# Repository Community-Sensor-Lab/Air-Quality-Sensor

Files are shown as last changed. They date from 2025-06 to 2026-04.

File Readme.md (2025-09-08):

<div align="center">

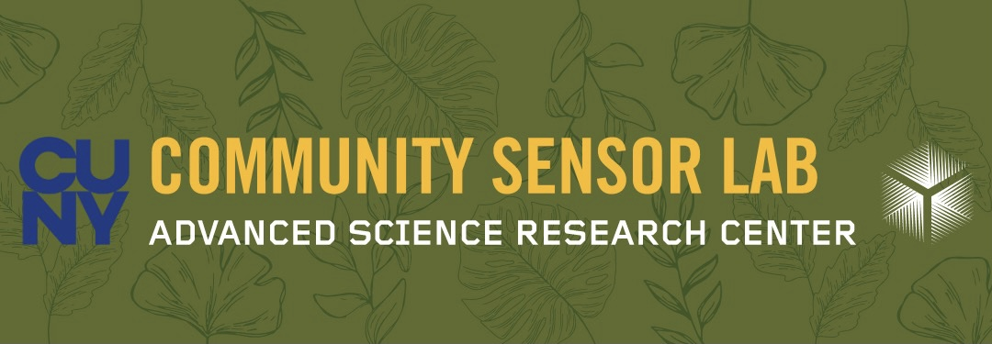
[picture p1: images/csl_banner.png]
Banner


</div>

#  Air Quality Sensor Assembly Guide

<div align="center">









*Build your own portable environmental monitoring station*

</div>

---

##  What You'll Build

<p align="center">
  
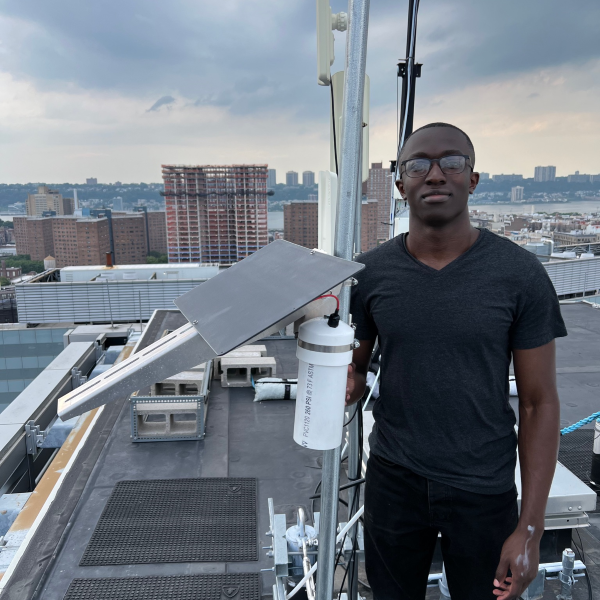
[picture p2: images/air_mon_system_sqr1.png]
  
</p>

> **A complete air quality monitoring system** that measures temperature, humidity, CO2, VOC/NOX, and particulate matter—with data logging, real-time display, and cloud connectivity.

###  Key Features
-  **Multi-sensor monitoring** (5 environmental parameters)
-  **SD card data logging** for long-term analysis  
-  **OLED display** for real-time readings
-  **WiFi connectivity** with Google Sheets integration
-  **Portable design** for indoor/outdoor use

###  Learning Outcomes
By completing this project, you'll gain hands-on experience with:
-  **Electronics assembly** and soldering techniques
-  **Arduino programming** and sensor integration
-  **Data visualization** and analysis methods
-  **IoT connectivity** and cloud services

---

##  Project Overview

| **Duration** | **Difficulty** | **Prerequisites** |
|:---:|:---:|:---:|
| 6-8 hours | Beginner | Basic computer skills |

*Multiple sessions recommended for best learning experience*

---

##  Complete Guide Contents

| Section | Title | Author | Description |
|:---:|---|---|---|
| **0** | [ Parts List](Contents/Parts-List.md) | *Mark* | Complete components inventory |
| **1** | [ Skills & Tools](Contents/1.%20Required-Skills-and-Tools.md) | *Lorena* | What you'll need to get started |
| **2** | [ Arduino Setup](Contents/2.%20Installing-Arduino-and-Getting-Started-2.3.6.md) | *Vincent* | Software installation & basics |
| **3** | [ Soldering Guide](Contents/3.%20Soldering-Pins-and-Headers-on-Boards.md) | | Hardware assembly techniques |
| **3.5** | [ WiFi Configuration](Contents/3.5%20Feather-M0-WiFi-Setup-Procedure.md) | *Fahmin: Flow chart* | Network connectivity setup |
| **4** | [ Component Assembly](Contents/4%20Breadboard-Assembly-and-Component-Code-Testing.md) | *Lorena* | Breadboard wiring & testing |
| **5** | [ Code Workshop](Contents/5.%20Code-Activity.md) | *Lorena* | Programming fundamentals |
| **6** | [ GitHub Integration](Contents/6.%20Downloading-CSL-AQS-Code-from-GitHub.md) | *Mark* | Source code management |
| **7** | [ Google Sheets Logging](Contents/7.%20Posting-to-Google-Logging-Spreadsheet.md) | *Vincent* | Cloud data integration |
| **8** | [ Data Visualization](Contents/8.%20How-to-Make-Data-Graphs-Lines-and-Time-Series.md) | *Ricardo* | Creating meaningful charts |
| **9** | [ PCB Design](Contents/9.%20Design-and-Assembly-of-PCB.md) | *Mark* | Printed Circuit Boards |
| **9.8** | [ Assembly of AQS Monitor on PCB Board](Contents/9.8%20Assembley-of-AQS-Monitor-on-PCB-Board.md) | | Soldering and mounting components onto the PCB |
| **10** | [ Final Assembly](Contents/10.%20AQS-PCB-Mount.md) | *Vincent* | Enclosure & mounting |

---

##  Quick Start

1. **Gather Materials** → Check the [Parts List](Contents/Parts-List.md)
2. **Setup Workspace** → Review [Skills & Tools](Contents/1.%20Required-Skills-and-Tools.md)
3. **Install Software** → Follow [Arduino Setup](Contents/2.%20Installing-Arduino-and-Getting-Started-2.3.6.md)
4. **Start Building!** → Begin with component assembly

---

##  Documentation Levels

| Guide Type | Best For | Link |
|---|---|---|
| **Quick Reference** | Experienced builders | *This README* |
| **Detailed Walkthrough** | First-time builders | [Comprehensive Guide](README-DETAILED.md) |

---

##  Perfect For

-  **STEM Education Programs**
-  **Students learning electronics**
-  **DIY environmental monitoring**
-  **Citizen science projects**

---

##  Contributing

Found an issue or have suggestions? We welcome contributions to improve this educational resource!

---

<div align="center">

**Transform your understanding of environmental monitoring while building something truly useful**





</div>

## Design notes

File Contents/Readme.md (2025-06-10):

# Air Quality Sensor Assembly Guide

## Introduction

This guide walks you through building an air quality monitoring system using Arduino-compatible components. The finished device will measure temperature, humidity, CO2, VOC/NOX, and particulate matter, log data to an SD card, display readings on an OLED screen, and optionally upload data to Google Sheets via WiFi.

This project is designed for students and educators in STEM programs, requiring basic electronics skills that will be developed throughout the assembly process. By completion, you'll have hands-on experience with soldering, Arduino programming, sensor integration, and data visualization.

**What you'll build:** A portable air quality sensor that can monitor indoor/outdoor air conditions and track environmental data over time.

**Time required:** Approximately 6-8 hours across multiple sessions

**Prerequisites:** Basic familiarity with computers and willingness to learn electronics fundamentals

> 📋 **Need more detail?** See the [comprehensive guide](README-DETAILED.md) with step-by-step breakdowns of each section.

## Contents

**0.** [Parts List](Parts-List.md) *(Mark)*

**1.** [Required Skills and Tools](1.%20Required-Skills-and-Tools.mdRequired-Skills-and-Tools.md) *(Lorena)*

**2.** [Installing Arduino and Getting Started](2.%20Installing-Arduino-and-Getting-Started.mdInstalling-Arduino-and-Getting-Started.md) *(Vincent)*

**3.** [Sensor Boards Soldering and Cables](3.%20Soldering-Pins-and-Headers-on-Boards.mdSoldering-Pins-and-Headers-on-Boards.md)

**3.5.** [Feather M0 WiFi Setup Procedure](3.5%20Feather-M0-WiFi-Setup-Procedure.mdFeather-M0-WiFi-Setup-Procedure.md)

**4.** [Setting Up Components](4%20Breadboard-Assembly-and-Component-Code-Testing.mdBreadboard-Assembly-and-Component-Code-Testing.md) *(Lorena)*

**5.** [Code Activity](5.%20Code-Activity.mdCode-Activity.md) *(Lorena)*

**6.** [Downloading CSL AQS Code from GitHub](6.%20Downloading-CSL-AQS-Code-from-GitHub.mdDownloading-CSL-AQS-Code-from-GitHub.md) *(Mark)*

**7.** [Posting to Google Logging Spreadsheet](7.%20Posting-to-Google-Logging-Spreadsheet.mdPosting-to-Google-Logging-Spreadsheet.md) *(Vincent)*

**8.** [How to Make Data Graphs - Lines and Time Series](8.%20How-to-Make-Data-Graphs-Lines-and-Time-Series.mdHow-to-Make-Data-Graphs-Lines-and-Time-Series.md) *(Ricardo)*

**9.** [Design and Assembly of PCB](9.%20Design-and-Assembly-of-PCB.mdDesign-and-Assembly-of-PCB.md) *(Mark)*

**10.** [AQS PCB Mount](10.%20AQS-PCB-Mount.mdAQS-PCB-Mount.md) *(Vincent)*

<!-- Internal Notes:
-make doc headers smaller
-gray pages on docs
-make 3d printed or wood chunk for trimming
-JST cables for pcb sen5 is different sequential order than breadboard connector
-add screw and jst cable to parts list
-new fritzing with jst ordering
-update markdown on github readme page & links to docs
-kendra compile docs as is 

Readme Extras:
-Cable making
-->

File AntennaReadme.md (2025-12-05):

# External Antenna
Welcome to the Community Sensor Lab's new addition, an external antenna. For site's with a unstable wireless connection.

This antenna builds upon the current AQS with the following components: 
* Adafruit Feather M0 WiFi with uFL
* WI-FI/Bluetooth Antenna 2.4/5.8GHZ
* SMA Female to IPX U.FL 
* SMA Antenna Extension Cable (6 ft) 
* SEN5X Mount V4 Antena.ipt (From our Content M_CAD Folder) 

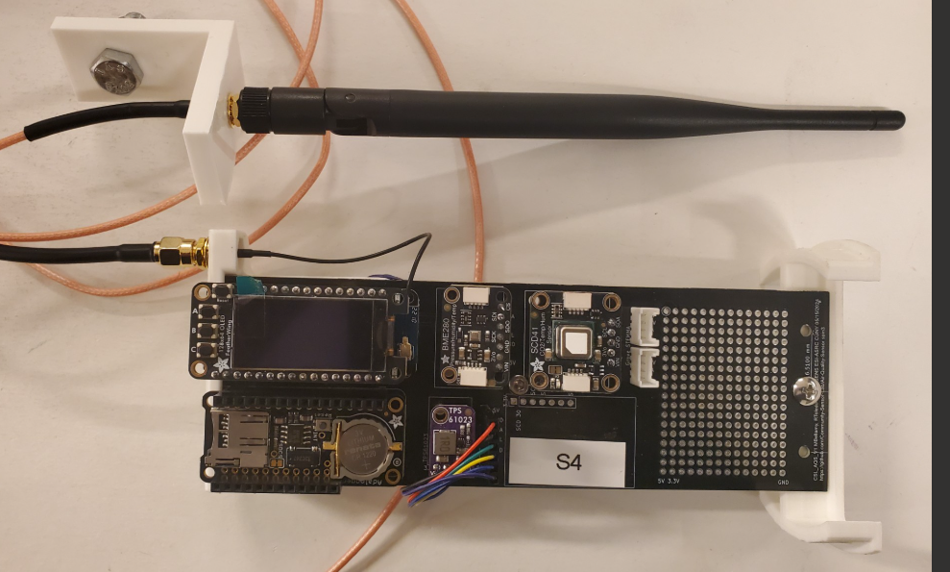
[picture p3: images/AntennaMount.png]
 

## Content
### Antenna Additions
* Parts List

## Antenna Additions
### Parts List

| Part Name | Part Image | Purchase Link|
|---|---|:---:|
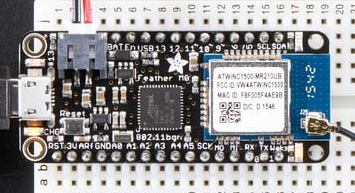
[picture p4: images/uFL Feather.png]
|Adafruit Feather M0 WiFi with uFL|  |[Adafruit](https://www.adafruit.com/product/3061)
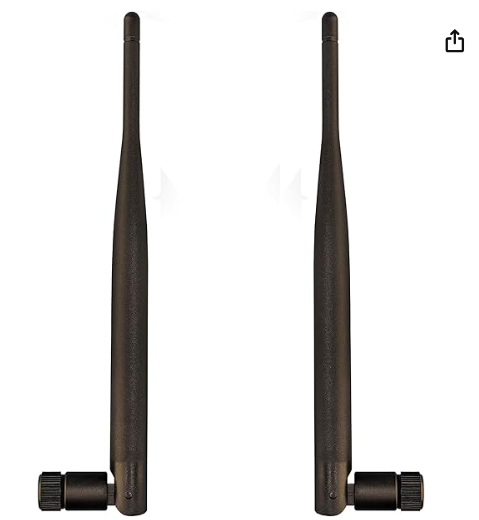
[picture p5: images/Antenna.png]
|WI-FI/Bluetooth Antenna 2.4/5.8GHZ|  |[Amazon](https://www.amazon.com/Dixingtek-SMA-Connector-Compatible-Security/dp/B0F2SMFZ9L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)
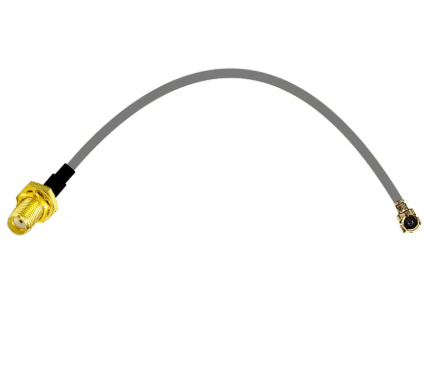
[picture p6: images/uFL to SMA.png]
|SMA Female to IPX U.FL|  |[Aliexpress](https://www.aliexpress.us/item/3256801652059536.html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)
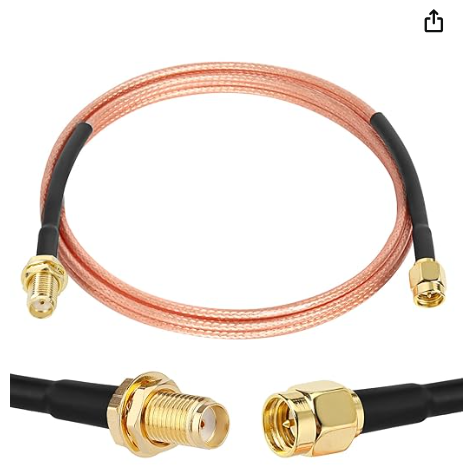
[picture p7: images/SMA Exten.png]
|SMA Antenna Extension Cable (6 ft)|  |[Amazon](https://www.amazon.com/dp/B0CL4P2LSS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)

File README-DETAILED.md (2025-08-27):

<div align="center">

Banner

</div>

#  Air Quality Sensor Assembly Guide
##  Detailed Step-by-Step Version

<div align="center">









*Complete educational walkthrough for building your environmental monitoring station*

</div>

---

##  About This Guide

This comprehensive guide provides **detailed, step-by-step instructions** for building an air quality monitoring system using Arduino-compatible components. Perfect for **classroom environments** and **self-paced learning**.

###  What You'll Build

<p align="center">
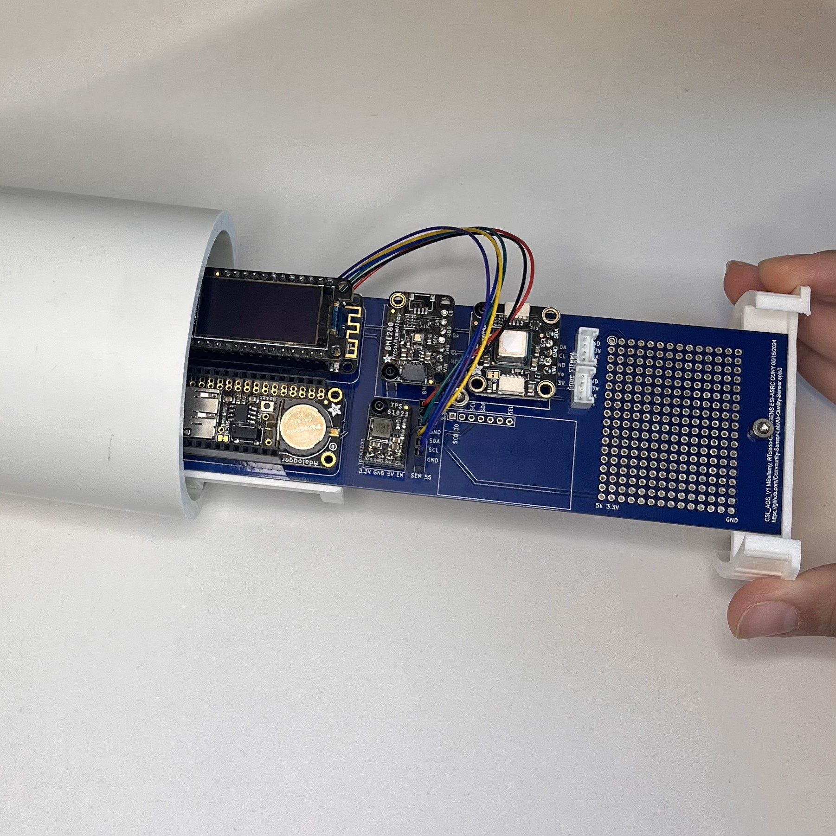
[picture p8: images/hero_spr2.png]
  
  
</p>

> **A complete air quality monitoring system** that measures temperature, humidity, CO2, VOC/NOX, and particulate matter—with data logging, real-time display, and cloud connectivity.

###  Project Specifications

| **Sensors** | **Data Storage** | **Connectivity** | **Display** |
|:---:|:---:|:---:|:---:|
| 5 Environmental | SD Card Logging | WiFi + Google Sheets | OLED Real-time |
| CO₂, VOC, PM2.5 | RTC Timestamps | Hotspot Provisioning | Serial Monitor |
| Temperature/Humidity | Offline Capable | Network Diagnostics | Status LEDs |

###  Educational Outcomes
By completing this detailed guide, students will master:
- **Hardware Skills**: Soldering, breadboarding, component assembly
- **Software Skills**: Arduino programming, library management, debugging
- **IoT Integration**: WiFi setup, cloud services, data visualization
- **Data Science**: Time series analysis, environmental monitoring concepts
- **Engineering Process**: Testing, troubleshooting, documentation

---

##  Quick Navigation

| **For Quick Start** | **For Deep Learning** |
|:---:|:---:|
|  [Streamlined Guide](Readme.md) |  *This Detailed Guide* |
| Perfect for experienced builders | Complete educational walkthrough |

---

##  Comprehensive Guide Contents

###  **Phase 1: Preparation & Setup**

| Section | Title | Author | Skills Developed | Duration |
|:---:|---|---|---|:---:|
| **0** | [ **Parts Inventory**](Contents/Parts-List.md) | *Mark* | Component identification, organization | 30 min |
| **1** | [ **Skills & Safety**](Contents/1.%20Required-Skills-and-Tools.md) | *Lorena* | Soldering, safety, tool usage, multimeter testing | 1 hour |
| **2** | [ **Arduino IDE Setup**](Contents/2.%20Installing-Arduino-and-Getting-Started-2.3.6.md) | *Vincent* | Software installation, board connection, basic programming | 45 min |

###  **Phase 2: Hardware Assembly**

| Section | Title | Author | Skills Developed | Duration |
|:---:|---|---|---|:---:|
| **3** | [ **Soldering Workshop**](Contents/3.%20Soldering-Pins-and-Headers-on-Boards.md) | | Advanced soldering, header installation, cable modification | 2 hours |
| **3.5** | [ **WiFi Provisioning**](Contents/3.5%20Feather-M0-WiFi-Setup-Procedure.md) | *Fahmin: Flow chart* | Network configuration, wireless setup | 30 min |
| **4** | [ **Breadboard Assembly**](Contents/4%20Breadboard-Assembly-and-Component-Code-Testing.md) | *Lorena* | Circuit building, sensor integration, testing procedures | 1.5 hours |

**Key Learning Points:**
- **Soldering Mastery**: Header pins, stacking headers, JST connector rewiring
- **Component Integration**: BME280 → SCD41 → SEN5x sensor chain
- **Power Management**: RTC battery installation, SD card formatting
- **Testing Protocols**: Serial monitor diagnostics, OLED status display

###  **Phase 3: Programming & Integration**

| Section | Title | Author | Skills Developed | Duration |
|:---:|---|---|---|:---:|
| **5** | [ **Code Integration**](Contents/5.%20Code-Activity.md) | *Lorena* | Code merging, programming logic, debugging | 45 min |
| **6** | [ **Firmware Deployment**](Contents/6.%20Downloading-CSL-AQS-Code-from-GitHub.md) | *Mark* | GitHub workflows, firmware flashing, troubleshooting | 30 min |

**Technical Focus:**
- **Code Architecture**: Understanding sensor libraries and data flow
- **Debugging Skills**: Serial output analysis, OLED diagnostics
- **Version Control**: GitHub integration, firmware management

###  **Phase 4: Data & Connectivity**

| Section | Title | Author | Skills Developed | Duration |
|:---:|---|---|---|:---:|
| **7** | [ **Cloud Integration**](Contents/7.%20Posting-to-Google-Logging-Spreadsheet.md) | *Vincent* | API integration, cloud services, data streaming | 45 min |
| **8** | [ **Data Visualization**](Contents/8.%20How-to-Make-Data-Graphs-Lines-and-Time-Series.md) | *Ricardo* | Time series analysis, graph creation, trend analysis | 1 hour |

**Data Science Skills:**
- **Cloud APIs**: Google Sheets integration, automated logging
- **Visualization**: Time series plots, environmental trend analysis
- **Analysis**: Pattern recognition in air quality data

###  **Phase 5: Professional Assembly**

| Section | Title | Author | Skills Developed | Duration |
|:---:|---|---|---|:---:|
| **9** | [ **PCB Design**](Contents/9.%20Design-and-Assembly-of-PCB.md) | *Mark* | PCB layout, professional assembly, manufacturing | 1 hour |
| **9.8** | [ **Assembly of AQS Monitor on PCB Board**](Contents/9.8%20Assembley-of-AQS-Monitor-on-PCB-Board.md) | | Soldering components, wiring sensors, PCB mounting | 50 min |
| **10** | [ **Enclosure Design**](Contents/10.%20AQS-PCB-Mount.md) | *Vincent* | 3D printing, mechanical design, product finishing | 45 min |

**Engineering Skills:**
- **PCB Development**: Design files, ordering process, assembly techniques
- **Mechanical Design**: 3D printed mounts, PVC enclosures
- **Product Integration**: Professional finish, deployment readiness

---

##  Learning Path Recommendations

###  **For Individual Learners**
1. **Start with Phase 1** → Build foundational skills
2. **Take breaks between phases** → Allow time for concept absorption
3. **Document your progress** → Keep a build journal
4. **Test thoroughly at each step** → Catch issues early

###  **For Classroom Use**
- **Session 1**: Parts inventory + Skills training (Sections 0-1)
- **Session 2**: Arduino setup + Soldering workshop (Sections 2-3)
- **Session 3**: Assembly + Testing (Section 4)
- **Session 4**: Programming + Cloud setup (Sections 5-7)
- **Session 5**: Data analysis + PCB assembly (Sections 8-10)

###  **For Experienced Builders**
- Use the [ Streamlined Guide](Readme.md) for faster assembly
- Reference this guide for detailed troubleshooting
- Focus on Phases 4-5 for advanced features

---

##  Important Prerequisites

###  **Knowledge Requirements**
-  Basic computer literacy
-  Willingness to learn electronics
-  Patience for step-by-step assembly
-  Basic understanding of environmental science (helpful)

###  **Required Equipment**
-  Soldering iron and supplies
-  Computer with USB port
-  Internet connection for downloads
-  Workspace with good lighting

---

##  Getting Help

###  **Support Resources**
- **Issues & Bugs**: Use GitHub Issues for technical problems
- **Discussion**: GitHub Discussions for general questions
- **Documentation**: Refer to individual section guides
- **Troubleshooting**: Each section includes diagnostic steps

###  **Success Indicators**
- [ ] All sensors reading valid data
- [ ] SD card logging timestamps
- [ ] OLED display showing current readings
- [ ] WiFi connected and uploading to Google Sheets
- [ ] Clean, professional assembly

---

##  Project Completion

Upon finishing this guide, you'll have:
- **A fully functional air quality monitoring station**
- **Real-time environmental data collection**
- **Cloud-connected data logging system**
- **Comprehensive electronics and programming skills**
- **Ability to analyze environmental trends**

---

<div align="center">

**Ready to get started? Follow the detailed sections above for complete assembly instructions.**





</div>

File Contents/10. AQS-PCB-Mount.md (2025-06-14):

# 3D Printing and Assembly Guide

## Finding Files
Files for both the PCB and Sensirion Mount will be located on the [Community Sensor Github](https://github.com/Community-Sensor-Lab/Air-Quality-Sensor/tree/master)

- Download and import the STL files into your 3D Printing Software
- Add supports wherever required

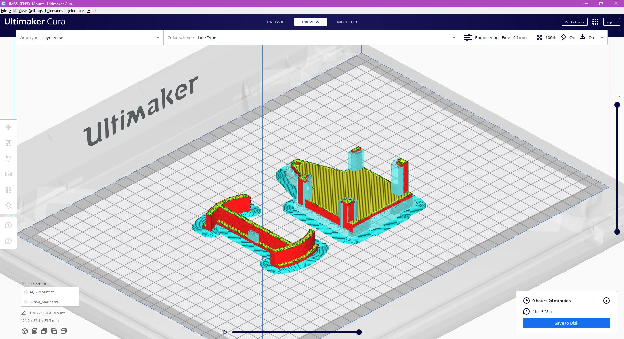
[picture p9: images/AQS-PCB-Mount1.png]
PCB Mount Overview


---

## Assembly Instructions

### Step 1: Thread Preparation
When the two mounts are completed, thread the holes with a 6-32 thread (Not required on newest mount iterations)

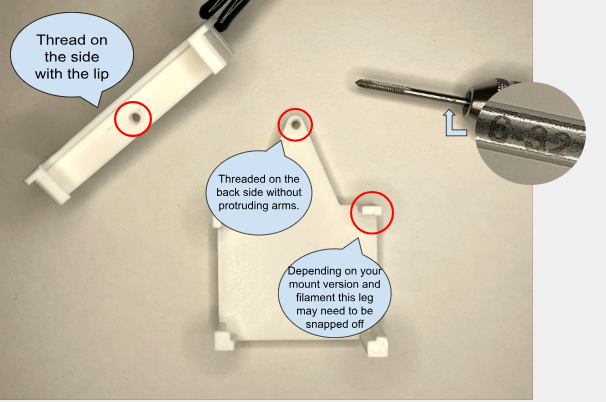
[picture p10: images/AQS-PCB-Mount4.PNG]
Threading the Mount


### Step 2: PCB Mount Installation
Secure the AQS Mount onto the top hole with a [Grainger #6 Screw](https://www.grainger.com/) (6-32 x 12" Phillips Head Screw) with a 6-32 lock nut and a Phillips Bit or 6-32 x 12" Screw with a 6-32 lock nut and a [H2.5 Bit](https://www.mcmaster.com/). 

**Important:** Make sure that the PCB is screwed into the side with the Lip so that the PCB will be secure in a vertical position.

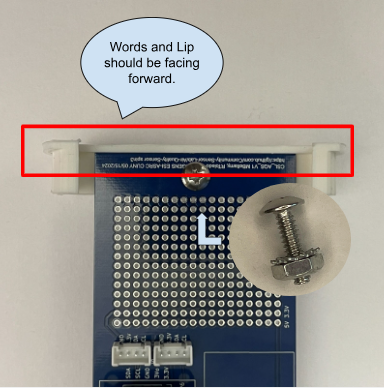
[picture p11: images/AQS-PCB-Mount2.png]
PCB Mount Installation


### Step 3: Sensor Installation
Insert the [SEN5X](https://sensirion.com/products/catalog/SEN54/) into the Mount

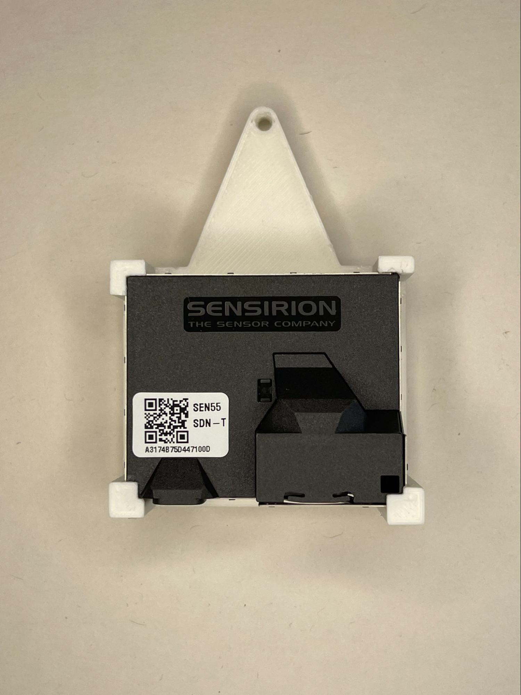
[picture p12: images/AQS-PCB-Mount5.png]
Sensor Installation


### Step 4: Alignment Check
Make sure that the holes line up for the SEN5X Mount and the PCB Board

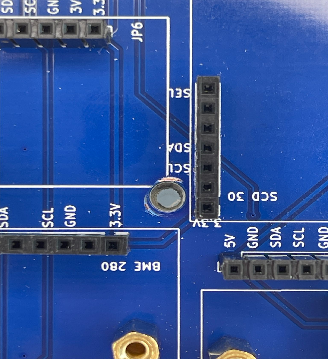
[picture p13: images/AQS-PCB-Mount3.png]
Alignment Check


### Step 5: Sensor Mount Security
Secure the SEN5X Mount using the hole in the middle of the PCB. Use a 6-32 x 12" Screw with a 6-32 lock nut and a H2.5 Bit or 6-32 x 12" Phillips Head Screw. 

**Note:** This mount should be on the back of the PCB with all the soldered joints.

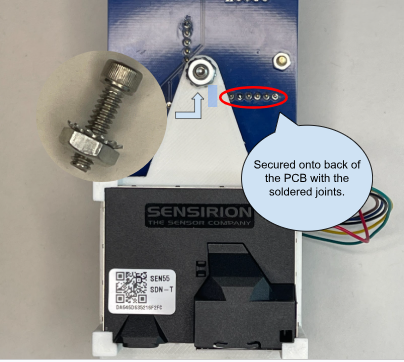
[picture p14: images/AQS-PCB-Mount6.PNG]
Sensor Mount Security


### Step 6: Final Assembly
Insert the AQS into a [3in PVC Pipe](https://www.homedepot.com/). It is a tight fit so try to use moderate pressure while rotating the AQS for it to be fully placed into the PVC Pipe.

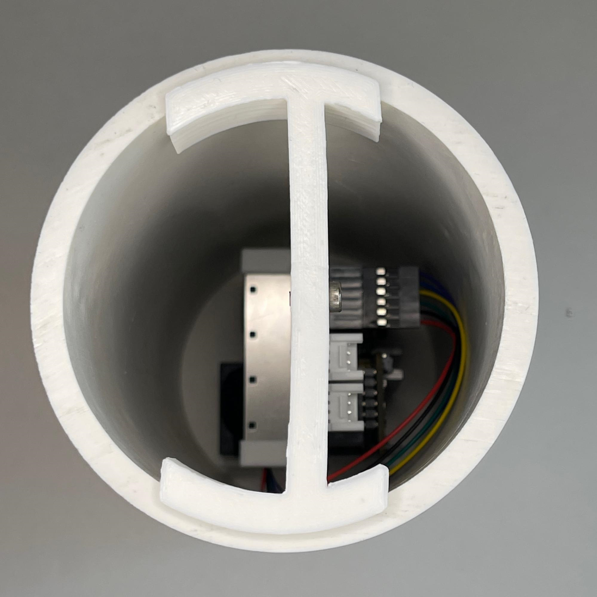
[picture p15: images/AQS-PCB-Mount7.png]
Final Assembly


---

## Required Materials
- 6-32 x 12" Phillips Head Screws
- 6-32 lock nuts
- Phillips screwdriver or H2.5 Bit
- 3" PVC Pipe
- SEN5X Sensor
- 3D printed PCB and Sensirion mounts

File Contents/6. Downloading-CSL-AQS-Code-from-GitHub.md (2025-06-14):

# Community Sensor Lab Air Quality Sensor Setup Guide

## Overview
The Community Sensor Lab's DIY Air Monitoring files include instructions on assembling and operating the air quality monitor. This guide will walk you through downloading the code, setting up your development environment, and configuring your sensor.

## Prerequisites
- Computer with internet access
- Air Quality Sensor hardware (Adafruit Feather M0)
- USB cable for connecting the sensor
- WiFi network credentials

---

## Step 1: Understanding GitHub and Accessing Our Code

[GitHub](https://github.com/) is an online platform where code is stored, shared, and collaboratively worked on. You **don't** need a GitHub account to visit the site or download the code.

### Accessing the Community Sensor Lab Repository

1. Visit: [Community Sensor Lab](https://github.com/Community-Sensor-Lab)
2. Go to the **Repositories** drop-down menu
3. Find and click on **Air-Quality-Sensor**

---

## Step 2: Exploring the Air Quality Sensor Repository

Once the [Air Quality Sensor Repository](https://github.com/Community-Sensor-Lab/Air-Quality-Sensor) opens, you'll see several important folders:

- **[CSL-AQS-V2.1](https://github.com/Community-Sensor-Lab/Air-Quality-Sensor/tree/master/CSL-AQS-V4)**: Contains all the code you need to run your Air Quality Sensor
- **[Images](https://github.com/Community-Sensor-Lab/Air-Quality-Sensor/tree/master/images)**: Contains all the images referenced in the [README.md file](https://github.com/Community-Sensor-Lab/Air-Quality-Sensor/blob/master/README.md), including instructions and additional information about AQS
- **[wifi_logger_proto.gs](https://github.com/Community-Sensor-Lab/Air-Quality-Sensor/blob/master/wifi_logger_proto.gs)**: Contains code for connecting the sensor to Google Sheets

---

## Step 3: Downloading the Code

1. Look for the green **Code** button  on the repository page
2. Click on it to reveal the dropdown menu
3. Under **HTTPS**, select **Download ZIP**

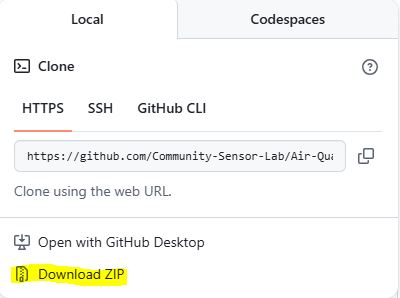
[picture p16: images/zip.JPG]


4. Click **Download ZIP** to start the download
5. Once the download is complete, locate the **Air-Quality-Sensor-master.zip** file
6. Extract the zip file:
   - **Windows**: Right-click the zip file and select "Extract All"
   - **macOS**: Double-click the zip file
   - **Linux**: Use your file manager or command line to extract
7. Save the extracted **Air-Quality-Sensor-master** folder in a location where you can easily find it again
8. **Important**: You will only need the **CSL-AQS-V2.1** folder for the main code
9. You can delete the zip file after extraction, but keep the images, README.md, and wifi_logger_proto.gs files for reference

---

## Step 4: Installing Arduino IDE

Before you can upload code to your sensor, you need to install the Arduino development environment.

### Installation Steps:

1. Visit the Arduino website: [https://www.arduino.cc/en/software](https://www.arduino.cc/en/software)
2. Scroll down and select the download version compatible with your operating system:
   - **Windows**: Windows Win 10 and newer
   - **macOS**: macOS Monterey or newer
   - **Linux**: Linux 64-bit
3. Follow the installation prompts based on your system
4. Once installed, open the Arduino IDE to confirm it's working correctly

### Installing Required Board Support:
1. Open Arduino IDE
2. Go to **Tools** > **Board** > **Boards Manager**
3. Search for "Adafruit SAMD" and install the **Adafruit SAMD Boards** package

---

## Step 5: Loading and Configuring the Code

### Opening the Code in Arduino IDE

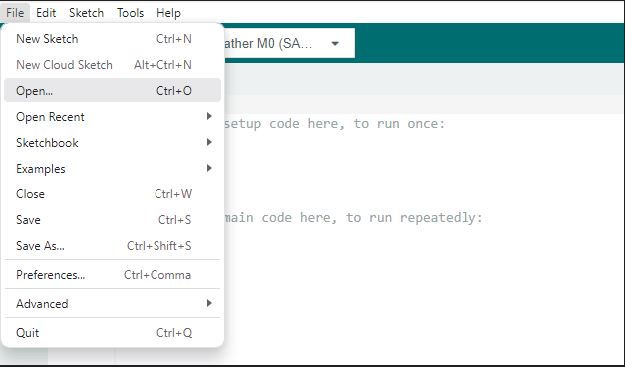
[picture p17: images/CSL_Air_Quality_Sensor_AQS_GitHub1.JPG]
Arduino IDE File Menu


1. In Arduino IDE, select **File** → **Open**
2. Navigate to your downloaded **CSL-AQS-V2.1** folder
3. Select the main `.ino` file to open the project

### Configuring Board Settings

Before **compiling** and **uploading** the code, you must configure the correct board and port settings.

#### Setting the Board:
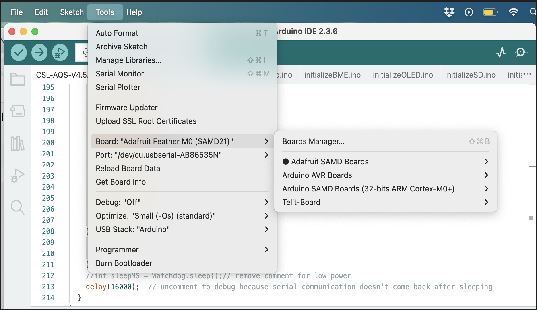
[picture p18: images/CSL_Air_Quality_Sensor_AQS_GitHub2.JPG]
Board Selection


1. Select **Tools** > **Board** > **Adafruit SAMD Boards** > **Adafruit Feather M0**
2. Verify the board name reads "Adafruit Feather M0 (SAMD21)"

#### Setting the Port:
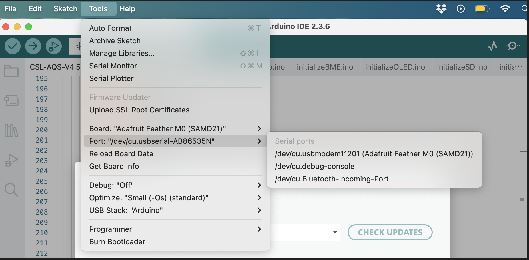
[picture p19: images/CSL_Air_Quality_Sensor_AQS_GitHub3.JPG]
Port Selection


1. Connect your Adafruit Feather M0 to your computer via USB
2. Select **Tools** > **Port** > **[Sensor Name]** (e.g., Adafruit Feather M0)
3. The port should match the Adafruit Feather M0 name (SAMD21)

### Compiling and Uploading the Code

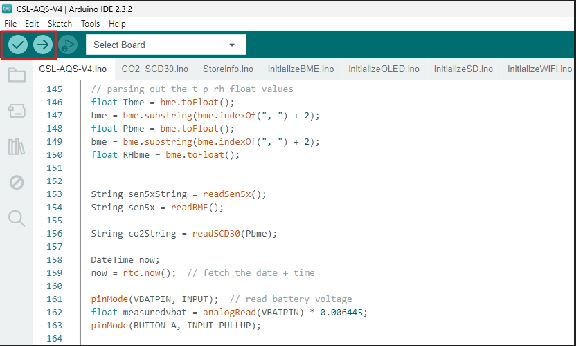
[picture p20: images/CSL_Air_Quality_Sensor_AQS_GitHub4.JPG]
Arduino IDE Toolbar


After reviewing the code, use the two buttons on the left side of the **Tool Bar**:

1. **Checkmark (✔)**: Click to **compile** the sketch and check for errors
2. **Right Arrow (➔)**: Click to **upload** the code to your sensor

**Note**: Always compile first to check for errors before uploading.

---

## Step 6: WiFi and Google Sheets Configuration

This step connects your sensor to your WiFi network and enables data logging to Google Sheets.

### WiFi Provisioning Process

The sensor needs to be provisioned (set up) to connect to your WiFi network. **Important**: The sensor must connect to a standard WiFi network (not enterprise networks with special authentication).

#### Provisioning Steps:

1. **Power on your sensor** - The OLED screen will display the sensor's temporary WiFi network name
2. **Connect your phone or computer** to the AQS system's WiFi network (shown on the OLED screen)
3. **Open a web browser** and navigate to: [https://192.168.1.1/](https://192.168.1.1/)
4. **Enter your WiFi credentials**:
   - WiFi network name (SSID)
   - WiFi password
5. **Click 'Submit'** to save the configuration
6. **Wait for confirmation** - The sensor will restart and connect to your WiFi network

### Google Sheets Integration (Optional)

If you want to log data to Google Sheets, refer to the `wifi_logger_proto.gs` file in the repository for detailed setup instructions.

---

## Troubleshooting

### Common Issues:

- **Board not detected**: Ensure USB cable is properly connected and drivers are installed
- **Compilation errors**: Check that you have the correct board package installed
- **WiFi connection fails**: Verify network credentials and ensure you're using a standard WiFi network
- **Upload fails**: Press the "RESET" button on the board two times to get the Feather M0 board ready to receive code

### Getting Help:

Visit the [Community Sensor Lab GitHub repository](https://github.com/Community-Sensor-Lab/Air-Quality-Sensor) for additional resources and community support.

---

## Next Steps

Once your sensor is configured and connected:
1. Monitor air quality readings on the OLED display
2. Access logged data through your configured Google Sheets (if set up)
3. Consider joining the Community Sensor Lab community for tips and collaboration

**Happy monitoring!**

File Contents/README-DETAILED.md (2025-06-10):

# Air Quality Sensor Assembly Guide - Detailed Version

## Introduction

This step-by-step guide walks you through building an air quality monitoring system using Arduino-compatible components. The finished device will measure temperature, humidity, CO2, VOC/NOX, and particulate matter, log data to an SD card, display readings on an OLED screen, and optionally upload data to Google Sheets via WiFi.

This project is designed for students and educators in STEM programs, requiring basic electronics skills that will be developed throughout the assembly process. By completion, you'll have hands-on experience with soldering, Arduino programming, sensor integration, and data visualization.

**What you'll build:** A portable air quality sensor that can monitor indoor/outdoor air conditions and track environmental data over time.

**Time required:** Approximately 6-8 hours across multiple sessions

**Prerequisites:** Basic familiarity with computers and willingness to learn electronics fundamentals

> 🚀 **Looking for a quick overview?** Check out the [streamlined guide](Readme.md).

## Detailed Contents

**0.** [Parts List](https://docs.google.com/document/d/1eruTOVNQ70D9B6PCWNkDp4wKfiiPEReuvoAi7Rmay4g/edit?usp=drive_link) *(Mark)*
- Students assemble all the parts in their own boxes

**1.** [Required Skills and Tools](https://docs.google.com/document/d/1mvQsTc32bjuC7l7ijtVF-_ARMnHwnhWfpPXzsSneSdQ/edit?usp=drive_link) *(Lorena)*
- Safety procedures and guidelines
- Materials and Tools overview
- Practice soldering techniques:
  - Using breadboard for practice
  - Freestyle soldering methods
- Wire stripping techniques
- Component mounting on breadboard
- Other essential tool usage
- Using multimeter for continuity testing (beep function)

**2.** [Installing Arduino and Getting Started](https://docs.google.com/document/d/1yBIu31yoNl-S-uk0izQ7rGxLrPd03uEbaEyvdvf0bEY/edit?usp=drive_link) *(Vincent)*
- Downloading and installing Arduino IDE
- Managing libraries and board packages
- Connecting Feather M0 and running Blink example:
  - USB connection setup
  - Finding the correct port
  - Running example Blink code to test connection

**3.** [Sensor Boards Soldering and Cables](https://docs.google.com/document/d/1qe-Vhb9ftH12_VpeKCsfD-ODc87dPtZxIyc3WNPK15M/edit?usp=drive_link)
- BME280 sensor header pin soldering
- SCD41 sensor header pin installation
- Rewiring JST connector cable for SEN5x sensor
- OLED display header pin soldering
- Feather M0 stacking header installation:
  - Proper soldering techniques
  - Trimming excess pin length
- Data logger stacking header setup:
  - Soldering best practices
  - Pin trimming for proper fit

**3.5.** [Feather M0 WiFi Setup Procedure](https://docs.google.com/document/d/1W8ZJhmlNl1G_N5n0yRctXMS5erIFklMhOZFekRmV0GQ/edit?usp=sharing)
- WiFi provisioning procedures
- Network configuration setup

**4.** [Setting Up Components](https://docs.google.com/document/d/1WFvF_7xLqt54y61l6RR8TfNEejDlFR1TU_Uz_Xx3njM/edit?usp=drive_link) *(Lorena)*
- Component placement on breadboard and USB connection
- Finding and selecting the active communication port
- Uploading and compiling the Blink test program
- SD card configuration:
  - Formatting SD card with SD Formatter tool
  - Running SD card example code for testing
- Real Time Clock (RTC) setup:
  - Installing coin battery for RTC backup power
  - Running RTC example to set current time
- Sensor explanation with datasheet references
- Step-by-step sensor placement on breadboard:
  - BME280 temperature/humidity sensor installation (must be installed first)
  - SCD30 CO2 sensor placement (note: BME280 dependency)

**5.** [Code Activity](https://docs.google.com/document/d/18pwJ7u2U9X6tMacqrYKDeCemcAeE9zQeEivDSDVQ8Qs/edit?usp=drive_link) *(Lorena)*
- Learning exercise: merging two example code bases
- Understanding code integration principles

**6.** [Downloading CSL AQS Code from Github](https://docs.google.com/document/d/1TifAqv9jKfEEz7CfKPhilbDQkyi2U0I-H0AbGaviCVQ/edit?usp=drive_link) *(Mark)*
- Step-by-step GitHub download process
- Running V4 firmware with offline capabilities
- Sensor troubleshooting using:
  - Serial monitor output analysis
  - OLED display diagnostic information
- WiFi and network ID (SSID) provisioning through hotspot setup

**7.** [Posting to Google Logging Spreadsheet](https://docs.google.com/document/d/1lNlVMkligkhTjbFhVWIEB8BZCj9COPIhkLUQ6nwG8GI/edit?usp=drive_link) *(Vincent)*
- Setting up Google Sheets integration
- Configuring automatic data logging
- Troubleshooting cloud connectivity issues

**8.** [How to Make Data Graphs - Lines and Time Series](https://docs.google.com/document/d/1v4I3emiJqDPMkTu0Ljfq2Lmtf5U1SFGffgOTqIotLh8/edit?usp=drive_link) *(Ricardo)*
- Creating effective data visualizations
- Time series graph configuration
- Analyzing air quality trends over time

**9.** [Design and Assembly of PCB](https://docs.google.com/document/d/1sCKWZlnZ-L1BZDOygIV_YUr5N8475Aq2Q2YT3bVnMBQ/edit?usp=drive_link) *(Mark)*
- PCB design file access and required software
- PCB ordering process and specifications
- Professional sensor assembly on custom PCB

**10.** [AQS PCB Mount](https://docs.google.com/document/d/1UT8rh22DokDd82nWzjSlzTCdgBBu4pW-yA3CvoBYW14/edit?usp=drive_link) *(Vincent)*
- 3D printing PCB mounting components
- Installing PCB mounts and housing in PVC tube enclosure

<!-- Internal Notes:
-make doc headers smaller
-gray pages on docs
-make 3d printed or wood chunk for trimming
-JST cables for pcb sen5 is different sequential order than breadboard connector
-add screw and jst cable to parts list
-new fritzing with jst ordering
-update markdown on github readme page & links to docs
-kendra compile docs as is 

Readme Extras:
-Cable making
-->

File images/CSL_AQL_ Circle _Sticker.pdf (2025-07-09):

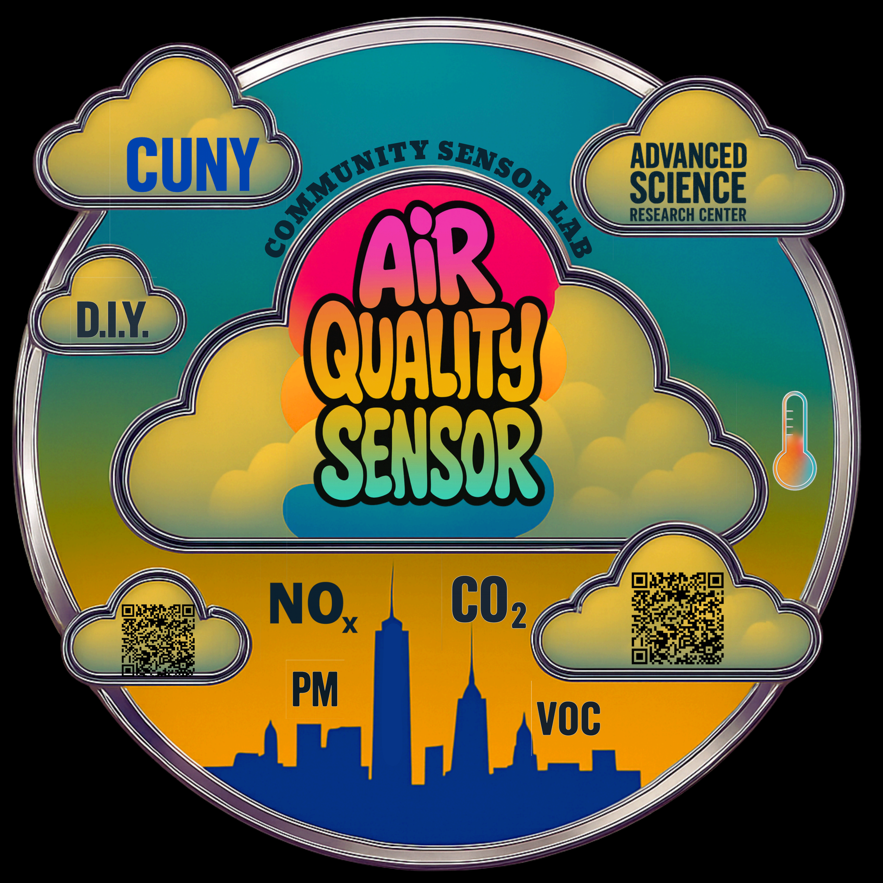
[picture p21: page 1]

COMMUNITY SENSOR LAB

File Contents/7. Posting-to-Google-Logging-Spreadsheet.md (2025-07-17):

# Air Quality Monitor - Google Logging Spreadsheet Setup Guide

## Overview

With a connection to a WiFi network, you can upload the data from the Air Quality Monitor to a Google spreadsheet in real time. To accomplish this, you must sign in using a Google account.

We have created a spreadsheet template where the data will be automatically uploaded. The Air Quality Monitor can be programmed to send data via WiFi, Bluetooth, or serial communication to a Google Spreadsheet using a deployment protocol, as outlined in document number 6.

---

## Part I: Getting Started with the Spreadsheet

### Step I: Access the Spreadsheet Template
Click on the link to access the spreadsheet:
**[📊 CSL-AQS-Template](https://docs.google.com/spreadsheets/d/137Ed-O1hPNgDt0UQk7bATeZ_9rmphRM5u2T0MZlxz-U/edit?usp=sharing)**

### Step II: Make a Copy
Once the spreadsheet opens, go to the **File → menu** and **Make a Copy** of the spreadsheet. It's important you make a copy because this is not a spreadsheet you can edit.

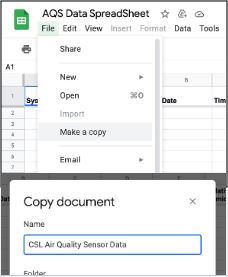
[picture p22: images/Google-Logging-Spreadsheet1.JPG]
File Menu - Make a Copy


### Step III: Save and Name Your Copy
Save the copy in your own Google Drive to be able to edit it.

**Name the spreadsheet** to identify the location, project, owner, or any other label that will help identify the data for the specific air monitor. If you can find the GPS coordinates, you can add this to the spreadsheet's name.

### Step IV: Review the Data Structure
Notice the different titles with respective units of the spreadsheet columns. Once you have completed these steps, your spreadsheet will collect data in real time!

---

## Part II: Deploying Google Script for Remote Data Upload

### Understanding the Technology

**Tool:** [Google Apps Script](https://developers.google.com/apps-script) - a cloud-based scripting language integrated into Google Sheets

**Purpose:** The script will automate the process of updating the Google Sheet

**How It Works:** The script uses HTTP methods (GET, POST, PUT, DELETE) to send or retrieve data to and from Google Sheets

We will use App Script to update the Google Sheet via HTTP. Google Apps Script makes creating and publishing add-ons for Google Docs, Sheets, Slides, and Forms easy. To learn more, visit **[Automate & extend Google Workspace with Simple Code](https://developers.google.com/apps-script)**.

### Step I: Open the Script Editor
To open the Script Editor, go to the **Extensions** drop-down menu and select **Apps Script**.

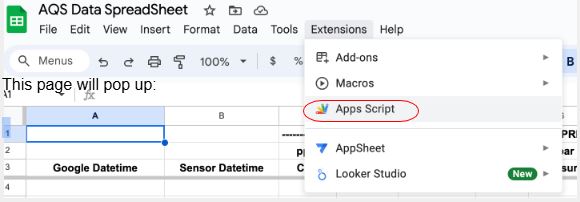
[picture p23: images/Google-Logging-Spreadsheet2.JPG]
Extensions Menu - Apps Script


This page will pop up:

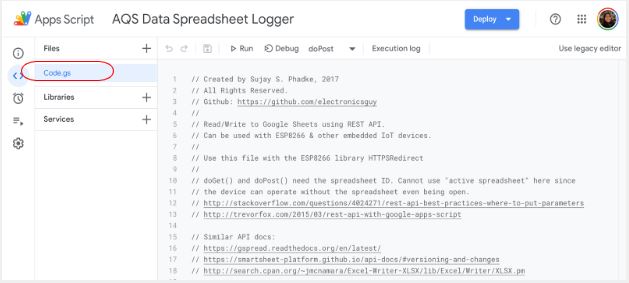
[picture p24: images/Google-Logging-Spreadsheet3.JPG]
Apps Script Editor Interface


The AQS (Air Quality Systems) Data Spreadsheet Logger will pop up. If you get an error message instead, see the [Troubleshooting section](#troubleshooting) below.

The AQS collects, records, and stores air quality data.

### Step II: Verify or Add Script Code
If you have followed these steps **with** the spreadsheet template we provided, you should see several lines of code when you open the script editor. The code will be needed for the following steps.

**If you did not use the template:**
1. You can find the code in our Air Quality Sensor repository: **[github.com/Community-Sensor-Lab/Air-Quality-Sensor](https://github.com/Community-Sensor-Lab/Air-Quality-Sensor)**
2. Locate the file: `WiFi_logger_proto.gs`
3. Copy the code in this file and paste it into the script editor

### Step III: Configure Your Spreadsheet ID

#### Modifying Spreadsheet Name and ID
2. **Line 55** is an important line that you need to edit (line number is different in image below)

Code Editor - Line 55

3. Line 55 says, `'enter id here.'` This line must be replaced with the **ID of your spreadsheet**. Every single Google Spreadsheet link has its unique ID

4. **To find the ID:** Return to your Google spreadsheet. The URL contains your spreadsheet ID

URL Structure Example

5. **Locate the ID:** The ID is located between the **d/** and the **/edit** of the URL. Copy this long string of characters and paste it between the quotation marks in the code, replacing the placeholder text: `"enter id here,"` as illustrated below:

Spreadsheet ID Location

6. **Test the Script:** Press **"RUN"**

---

## Part III: Deploying Your App Script

### Step IV: Deploy the Application

Now that your App Script is ready, you must deploy it. An App Script deployment is a version of the script made available for use as a web app, add-on, or API executable.

1. **Deploy:** Go to the **Deploy** drop-down menu, and select **→ Manage Deployment**

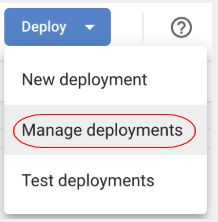
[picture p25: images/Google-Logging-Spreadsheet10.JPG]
Deploy Menu


2. **Configuration:** The Configuration window will pop up

3. **Select Type:** Under the Menu Select **Type**, Select **Web app**

4. **New description:** Provide a brief and clear explanation of the script's purpose  
   Example: "automates data entry and processing for Google Sheets"

5. **Web app:** Write the email you used to complete this process in the Web App section

6. **Who has access:** Using the drop-down menu, choose **Anyone**. Selecting "Anyone" allows any user who visits the web app link to execute it, making it easier to share without requiring a Google credential

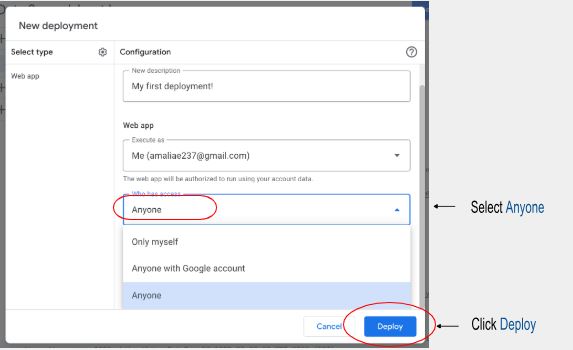
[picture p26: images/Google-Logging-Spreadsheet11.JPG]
Configuration Window Settings


### Step V: Authorization Process

1. **New Deployment:** Click on the **"Authorize Access"** button

Authorize Access Button

2. **Authorization:** Once you click Authorize access, the AQS Data Spreadsheet Logger screen will pop up requesting access to your Google Account

3. **Security Warning:** Another screen will pop up - click on **Go to AQS Data Spreadsheet Logger (unsafe)**

Authorization Dialog
⟵ Click the **Allow** button

Security Warning Screen

↑ Click Go to AQS Data Spreadsheet Logger (unsafe)

4. **Advanced Options:** Ignore this message - Google hasn't verified this app. Go to the bottom of the page and click on **Advanced**

Advanced Security Options

Final Authorization Screen

---

## Troubleshooting

### Script Editor Access Issues

**Problem:** If you get an error message window when trying to access the Script Editor

Error Message Example

Account Selection Error
⟵ **Default email**

**Cause:** You are most likely not using your default Google account for your spreadsheet

Notice that the *Default email* is different than the one that appears on the error message.

**Solution:**
- You must sign out of your default Google account to correct this issue
- This may require signing out of all your accounts, as Google doesn't allow signing out of only one account when multiple accounts are signed in simultaneously
- Once you have signed out, you can sign in to your default account

**Steps to resolve:**
1. Sign in to the account you are using to access your Google Sheets
2. Once you sign into that account, return to the spreadsheet
3. Try opening the script editor again

### Common Issues and Solutions

- **Permission Errors:** Ensure you're consistently using the same Google account throughout the process
- **Spreadsheet ID Errors:** Double-check that you copied the complete ID string from the URL
- **Authorization Problems:** Follow the security warning steps carefully, even if they appear "unsafe"

---

## Additional Resources

- **[Google Apps Script Documentation](https://developers.google.com/apps-script)**
- **[Community Sensor Lab GitHub Repository](https://github.com/Community-Sensor-Lab/Air-Quality-Sensor)**
- **[Google Sheets API Reference](https://developers.google.com/sheets/api)**

---

## Next Steps

Once your deployment is complete, your Air Quality Monitor will be configured to automatically send data to your Google Spreadsheet. The system will collect, record, and store air quality data in real time, making it accessible for analysis and sharing with your community.

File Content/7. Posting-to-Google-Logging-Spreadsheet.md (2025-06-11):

**Getting Started with a Spreadsheet**

With a connection to a WiFi network, you can upload the data from the Air Quality Monitor to a Google spreadsheet in real time. To accomplish this, you must sign in using a Google account.

We have created a spreadsheet template where the data will be automatically uploaded. The Air Quality Monitor can be programmed to send data via WiFi, Bluetooth, or serial communication to a Google Spreadsheet using a deployment protocol, as outlined in document number 6\. The spreadsheet template can be accessed using the link below.

**Step I**. Click on the link to access the spreadsheet. [CSL-AQS-Template](https://docs.google.com/spreadsheets/d/1c2Fz-3yoDlgtHRTSywHb1Qw0Rqlr5v1rYq2KaVxd2Ac/edit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) 

****

**Step II:** Once the spreadsheet opens, go to the **File \-\> menu** and **Make a Copy** of the spreadsheet. It’s important you make a copy because this is not a spreadsheet you can edit.

**Step III.** Save the copy in your own Google Drive to be able to edit it.   
**Name the spreadsheet** to identify the location, project, owner, or any other label that will help identify the data for the specific air monitor. If you can find the GPS coordinates, you can add this to the spreadsheet's name.

**Step IV.** Notice the different titles with respective units of the spreadsheet columns. Once you have completed these steps, your spreadsheet will collect data in real time\!

**Part II. Deploying Google Script for Remote Data Upload**

**Understanding this Tool:** We will use **Google App Script,** a cloud-based scripting language integrated into Google Sheets. 

**Purpose:** The script will automate the process of updating the Google Sheet.

**How It Works:** The script uses **HTTP** methods (GET, POST, PUT, DELETE) to send or retrieve data to and from **Google Sheets.**

We will use App Script to update the Google Sheet via **HTTP.**

Google Apps Script makes creating and publishing add-ons for Google Docs, Sheets, Slides, and Forms easy. To learn more, visit [Automate & extend Google Workspace with Simple Code.](https://developers.google.com/apps-script) 

**Step I.** To open the Script Editor, go to the **Extensions** drop-down menu and select **Apps Script.**

This page will pop up:

The AQS (Air Quality Systems) Data Spreadsheet Logger will pop up. If you get an error message instead, see the Troubleshooting instructions below. 

The AQS collects, records, and stores air quality data. 

---

**Troubleshooting:** If you get an error message window, you are most likely not using your default Google account for your spreadsheet.

* You must sign out of your default Google account to correct this issue.   
* This may require signing out of all your accounts, as Google doesn’t allow signing out of only one account when multiple accounts are signed in simultaneously.   
* Once you have signed out, you can sign in to your default account.

Sign in to the account you are using to access your Google Sheets. Once you sign into that account, return to the spreadsheet and try opening the script editor again.   
---

**Step III. Updating Google Script Code**

If you have followed these steps **with** the spreadsheet **template** we provided, you should see several lines of code when you open the script editor. The code will be needed for the following steps. 

1. If you **did not** use the template, you can find the code in our Air Quality Sensor repository, [github.com/Community-Sensor-Lab/Air-Quality-Sensor,](https://github.com/Community-Sensor-Lab/Air-Quality-Sensor) in the file WiFi\_logger\_proto.gs. Copy the code in this file and paste it into the script editor.

---

**Modifying Spreadsheet Name and ID**

2. Line 55 is an important line that you need to edit (line number is different in image below). 

3. Line 55 says, ‘enter id here.’ This line must be replaced with the **ID of your spreadsheet**. Every single Google Spreadsheet link has its unique ID.

4. To find the ID, return to your Google spreadsheet. The URL contains your spreadsheet ID.  
5. The ID is located between the **d/** and the **/edit** of the URL. Copy this long string of characters and paste it between the quotation marks in the code, replacing the placeholder text:  “enter id here,” as illustrated below:

6. Press “RUN” 

**Step IV. Deploying App Script**

Now that your App Script is ready, you must deploy it. An App Script deployment is a version of the script made available for use as a web app, add-on, or API executable. 

1. **Deploy:** Go to the Deploy drop-down menu, and select \-\> Mangage Deployment.

2. **Configuration:** The Configuration window will pop up.    
3. **Select Type:** Under the Menu Select Type, Select Web app.  
4. **New description:** Provide a brief and clear explanation of the script’s purpose. Example: “automates data entry and processing for Google Sheets”  
5. **Web app:** Write the email you used to complete this process in the Web App section.    
6. **Who has access:** Using the drop-down menu, choose Anyone. Selecting “Anyone” allows any user who visits the web app link to execute it, making it easier to share without requiring a Google credential.        

**Step V: Authorization**

1. **New Deployment:** Click on the “Authorize Access” button.

2. **Authorization:** Once you click Authorize access, the AQS Data Spreadsheet Logger screen will pop up requesting access to your Google Account.   
3. Another screen will pop up \- click on Go to AQS Data Spreadsheet Logger (unsafe)

                          ↑    Click Go to AQS Data Spreadsheet Logger (unsafe)

4. Ignore this message \- Google hasn’t verified this app. Go to the bottom of the pace and click on Advanced.

[image1]: <>

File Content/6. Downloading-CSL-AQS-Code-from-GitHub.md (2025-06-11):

  
**Downloading the CSL Air Quality Sensor (AQS) Code from GitHub**

**Step I. Using GitHub** 

The Community Sensor Lab’s DIY Air Monitoring files include instructions on assembling and operating the air quality monitor. The files can be accessed on GitHub using the link below\! 

Visit:  [Community Sensor Lab](https://github.com/Community-Sensor-Lab)  ↓

[GitHub](https://github.com/) is an online platform where code is stored, shared, and collaboratively worked on. You **don't** need a GitHub account to visit the site or download the code. 

You can access our files by following the instructions on The Community Sensor Lab's GitHub page\! 

Visit:  [Community Sensor Lab](https://github.com/Community-Sensor-Lab)  ↓ 

1. Go to the **Repositories** drop-down menu.  
     
2. Find and click on Air-Quality-Sensor.

---

**Step II. Air-Quality-Sensor Repository**  

3. Once the [Air Quality Sensor Repository](https://github.com/Community-Sensor-Lab/Air-Quality-Sensor) opens, it will display all the folders in the file.

4. The first folder, [CSL-AQS-V2.1](https://github.com/Community-Sensor-Lab/Air-Quality-Sensor/tree/master/CSL-AQS-V4), has all the code you need to run your Air Quality Sensor.

5. The '[Images](https://github.com/Community-Sensor-Lab/Air-Quality-Sensor/tree/master/images)' folder contains all the images referenced in the [README.md file](https://github.com/Community-Sensor-Lab/Air-Quality-Sensor/blob/master/README.md), including instructions and additional information about AQS.

6. The file [wifi\_logger\_proto.gs](https://github.com/Community-Sensor-Lab/Air-Quality-Sensor/blob/master/wifi_logger_proto.gs) contains code for connecting the sensor to Google Sheets. 

**Step III. Downloading Code** 

7. It will prompt a couple of options on the menu bar. Under HTTPS, scroll down and select Download Zip.

8. Click on Download ZIP. Once the download is complete, click on the Air-Quality-Sensor-master.zip file. A blue folder named Air-Quality-Sensor-master will appear. If you’re using Windows, follow the standard procedure to extract files.  
      
9. Save this folder in a location where you can easily find it again.   
     
10. Open the zip file. Once the blue folder appears, you can delete the zip file.

11.  The Air-Quality-Sensor-master has several folders; you will only need the  CSL-AQS-V2.1 folder.   
      
12. **Delete** the images, README.md, and wifi\_logger\_proto.gs. folders.

**Step IV. Installing Arduino** 

Instructions for Installing Arduino IDE:

1. Visit the Arduino website: [https://www.arduino.cc/en/software](https://www.arduino.cc/en/software)  
2. Scroll down and select the download version compatible with your operating system: Windows, macOS, or Linux.  
3. Follow the installation prompts based on your system.  
4. Once installed, open the Arduino IDE to confirm it's working correctly.

---

**Running the Code in the Arduino Microcontroller**

****  
To open the code in Arduino, select File→Open and select the downloaded  CSL-AQS-(insert version) folder. 

Before **compiling** and **uploading** the code, check the **Board Name** so that it reads (Adafruit Feather M0 (SAMD21) and the **Port** should also have the same name as the Board (Adafruit Feather M0 (SAMD21).

	For the board:

Select Tools \> Board \> Adafruit SAMD Boards \> Adafruit Feather M0



For the Port Connection: 

Select Tools \> Port \> (Sensor Name) \[Ex: Adafruit Feather M0\] \- Matches the Adafruit Feather M0 name (SAMD21).



After reviewing the code, use the two buttons on the left side of the **Tool Bar**  (check mark ✔ and right arrow ➔). The check mark ✔ will **Compile** the sketch and the right arrow ➔ will **Upload** the code.



**Provisioning the WiFi and Google Sheet credentials**

This step connects the system to the available Wi-Fi network (it must be a standard Wi-Fi network). 

The code will have to go through provisioning (setup). During this step, connect your phone to the AQS system's Wi-Fi network, which will be displayed on the OLED screen. 

The steps required for this are:

* Connect to the AQS systems' WiFi network.  
    
* Access the internet and go to [https://192.168.1.1/](https://192.168.1.1/)  
    
* Enter your Wi-Fi network and password, and then select ‘Submit’.

[image1]: <>

[image2]: <>

[image3]: <>

[image4]: <>

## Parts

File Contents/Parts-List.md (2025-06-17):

**Featherwing Components**

| Component | Image | Description | Link |
| ---- | ---- | ---- | ---- |
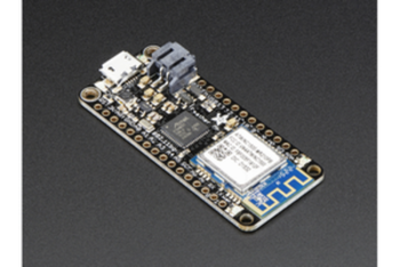
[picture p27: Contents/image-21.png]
Feather M0 WiFi
| Feather M0 WiFi (WINC1500) |  | Microcontroller and Wifi Radio <br> It is equivalent to the CPU <br> of a computer. | [Adafruit Store](https://www.adafruit.com/product/3010) |
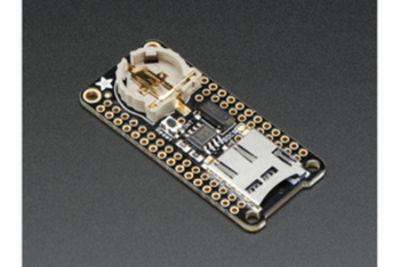
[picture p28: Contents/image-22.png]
Featherwing Logger
| Featherwing Logger (RTC microSD) |  | Real-time Clock and MicroSD Reader <br> It works like the memory <br> and data storage of a computer. | [Adafruit Store](https://www.adafruit.com/product/2922) |
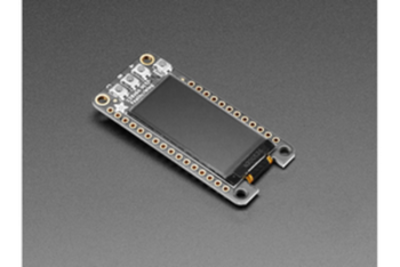
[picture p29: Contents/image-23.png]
Featherwing OLED
| Featherwing OLED 128x64 |  | Display <br> It is equivalent to the computer screen. | [Adafruit Store](https://www.adafruit.com/product/4650) |

**Sensors**

| Component | Image | Description | Link |
| ---- | ---- | ---- | ---- |
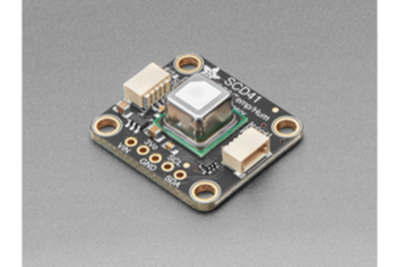
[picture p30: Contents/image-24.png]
Adafruit SCD41 CO2
| Adafruit SCD41 CO2 |  | CO2 Sensor | [Adafruit Store](https://www.adafruit.com/product/5190) |
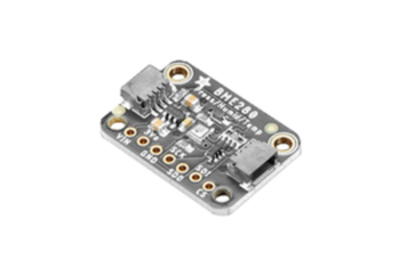
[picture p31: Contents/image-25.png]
BME280 Sensor
| BME280 Temp. Press. Rel Humidity |  | Temp. Pressure Humidity Sensor | [DigiKey](https://www.digikey.com/en/products/detail/adafruit-industries-llc/2652/5604372) |
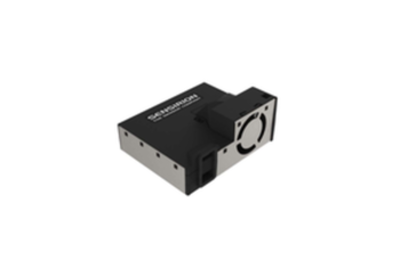
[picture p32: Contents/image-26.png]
Sensirion SEK-SEN5X
| Sensirion SEK-SEN5X |  | Particulate Matter/VOC/NOX Sensor | [DigiKey](https://www.digikey.com/en/products/detail/sensirion-ag/SEN55-SDN-T/16342756) |

**Additional Parts**

| Part | Image | Description | Link |
| ---- | ---- | ---- | ---- |
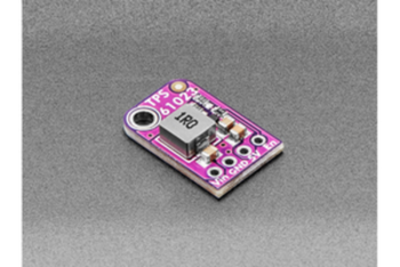
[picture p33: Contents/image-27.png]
MiniBoost 5V
| MiniBoost 5V |  | 3.3 to 5 Voltage Converter | [Adafruit Store](https://www.adafruit.com/product/4654) |
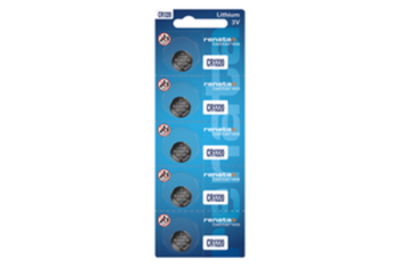
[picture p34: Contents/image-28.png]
Battery Coin cr1220
| Battery Coin cr1220 |  | Battery (Coin) | [DigiKey](https://www.digikey.com/en/products/detail/renata-batteries/RENATA-CR1220-TS-1/13283109) |
| Micro SD | Micro SD | (Physical) Data Storage | [DigiKey](https://www.digikey.com/en/products/detail/delkin-devices-inc/USDCOEM-16GB/13882332) |
| 4 Pin Headers | 4 Pin Headers | 4 Pin Header for 3.3 to 5 Volt. Converter | [DigiKey](https://www.digikey.com/en/products/detail/sullins-connector-solutions/PPTC041LFBN-RC/810144) |
| 5 Pin Headers | 5 Pin Headers | 5 Pin Header for SCD 41 | [DigiKey](https://www.digikey.com/en/products/detail/sullins-connector-solutions/PPTC051LFBN-RC/807239) |
| 6 Pin Headers | 6 Pin Headers | 6 Pin Header for Particulate Matter Sensor | [DigiKey](https://www.digikey.com/en/products/detail/würth-elektronik/61300611821/16608482) |
| 7 Pin Headers | 7 Pin Headers | 7 Pin Header for BME280 and SCD30 | [DigiKey](https://www.digikey.com/en/products/detail/sullins-connector-solutions/PPTC071LFBN-RC/810146) |
| 12 Pin Headers | 12 Pin Headers | 12 Pin Header for Feather Logger and M0 | [DigiKey](https://www.digikey.com/en/products/detail/sullins-connector-solutions/PPTC121LFBN-RC/807231) |
| 16 Pin Headers | 16 Pin Headers | 16 Pin Header for Feather Logger and M0 | [DigiKey](https://www.digikey.com/en/products/detail/sullins-connector-solutions/PPTC161LFBN-RC/810154) |
| Feather Stacking Header Set | Feather Stacking Header Set | Stacking header for Feather M0 | [Adafruit Store](https://www.adafruit.com/product/2830) |
| Grove Female Header - DIP-4P-2.0mm | Grove Female Header | i2c Grove Connector | [Seeed Studio](https://www.seeedstudio.com/Grove-Universal-4-pin-connector.html) |
| CSL_AQS_V1 PCB Board (KiCAD) | CSL_AQS_V1 PCB Board | PCB Board | [PCBWay](https://www.pcbway.com/) / [GitHub](https://github.com/Community-Sensor-Lab/Air-Quality-Sensor/tree/CSL_AQS_V5) |
| PVC Tube | PVC Tube | PVC 3 Inch Diameter 7 Inch LengthTube | [Home Depot](https://www.homedepot.com/p/Charlotte-Pipe-3-in-x-2-ft-PVC-DWV-Sch-40-Pipe-PVC073000200HA/100533056) |
| PVC Cap | PVC Cap | PVC Cap 3 Inch Diameter | [Home Depot](https://www.homedepot.com/p/3-in-PVC-DWV-Cap-PVC001161000HD/203393254) |
| Type C Cable | Type C Cable | Micro USB Cable | [Amazon](https://www.amazon.com/Ruaeoda-Micro-Android-Charger-Gold-Plated/dp/B0D7RZJSPS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) |
| Grainger #6 Screw | Grainger #6 Screw Socket Head | 6-32 x 1/2'' Socket Head Screw | [McMaster-Carr](https://www.mcmaster.com/catalog/130/3555/92196A146) |
| Grainger #6 Screw | Grainger #6 Screw Phillip Head | 6-32 x 1/2'' Phillip Head Screw | [Amazon](https://a.co/d/00aQRtf8) |
| 6#-32 Lock Nuts | 6#-32 Lock Nuts | 6#-32 Lock Nuts | [Amazon](https://www.amazon.com/dp/B09V2SMKCS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) |
| 11mm, M2.5 Standoffs | 11mm, M2.5 Standoffs | 100 Pcs M2.5 11mm Standoffs | [Amazon](https://www.amazon.com/dp/B0BK99T8S4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) |
| Hex Nuts, M2.5x0.45mm | Hex Nuts, M2.5x0.45mm | 100 Pcs M2.5x0.45mm Hex Nuts | [Amazon](https://www.amazon.com/dp/B07H3WGLJN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) |
| M2.5x6mm Screws | M2.5x6mm Screws | 100 Pcs M2.5x6mm Screws | [Amazon](https://www.amazon.com/dp/B01B1PGR22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) | |

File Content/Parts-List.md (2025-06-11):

**Adafruit Feather (Arduino) Components**

| Component | Image | Description | Link |
| :---- | :---- | :---- | :---- |
| Feather M0 WiFi (WINC1500) | Feather M0 Wifi | Microcontroller CPU, battery charger and WiFi Radio. The 'brains' of the system. | [https://www.adafruit.com/product/3010](https://www.adafruit.com/product/3010) |
| Addalogger Featherwing: RTC & MicroSD | Addalogger_Featherwing Addalogger Featherwing | Real-time Clock and MicroSD Read/Write. It is the 'hard drive' data storage of the system. It also has a Real Time Clock (RTC) to keep date and time even when turned off. | [https://www.adafruit.com/product/2922](https://www.adafruit.com/product/2922) |
| Featherwing OLED 128x64 | FeatherWing_OLED FeatherWing OLED | The Organic Light Emmitting Diode (OLED) Display provides visual information from the system. | [https://www.adafruit.com/product/4650](https://www.adafruit.com/product/4650) |

**Sensors**

| Component | Image | Description | Link |
| :---- | :---- | :---- | :---- |
| Adafruit SCD41 CO2 | Adafruit_SCD41-CO2 Adafruit SCD-41 | CO2 Sensor | [https://www.adafruit.com/product/5190](https://www.adafruit.com/product/5190) |
| BME280 Temp. Press. Rel Humidity | Adafruit_BME280 Adafruit BME280 | Temp. Pressure Humidity Sensor | [https://www.adafruit.com/product/2652](https://www.adafruit.com/product/2652) |
| Sensirion SEK-SEN5X | SEN55_PM-AQS | Particulapngte Matter/VOC/NOX Sensor | [https://www.digikey.com/en/products/detail/sensirion-ag/SEN55-SDN-T/16342756](https://www.digikey.com/en/products/detail/sensirion-ag/SEN55-SDN-T/16342756) |

**Additional Parts**

| Part | Image | Description | Link |
| :---- | :---- | :---- | :---- |
| MiniBoost 5V | ![][image7] | 3.3 to 5 Voltage Converter | [https://www.adafruit.com/product/4654](https://www.adafruit.com/product/4654) |
| Battery Coin cr1220 | ![][image8] | Battery (Coin) | [https://www.digikey.com/en/products/detail/renata-batteries/RENATA-CR1220-TS-1/13283109](https://www.digikey.com/en/products/detail/renata-batteries/RENATA-CR1220-TS-1/13283109) |
| Micro SD | ![][image9] | (Physical) Data Storage | [https://www.digikey.com/en/products/detail/delkin-devices-inc/USDCOEM-16GB/13882332](https://www.digikey.com/en/products/detail/delkin-devices-inc/USDCOEM-16GB/13882332) |
| 4 Pin Headers | ![][image10] | 4 Pin Header for 3.3 to 5 Volt. Converter | [https://www.digikey.com/en/products/detail/sullins-connector-solutions/PPTC041LFBN-RC/810144](https://www.digikey.com/en/products/detail/sullins-connector-solutions/PPTC041LFBN-RC/810144) |
| 5 Pin Headers | ![][image11] | 5 Pin Header for SCD 41  | [https://www.digikey.com/en/products/detail/sullins-connector-solutions/PPTC051LFBN-RC/807239](https://www.digikey.com/en/products/detail/sullins-connector-solutions/PPTC051LFBN-RC/807239) |
| 6 Pin Headers | ![][image12] | 6 Pin Header for Particulate Matter Sensor | [https://www.digikey.com/en/products/detail/w%C3%BCrth-elektronik/61300611821/16608482](https://www.digikey.com/en/products/detail/w%C3%BCrth-elektronik/61300611821/16608482) |
| 7 Pin Headers | ![][image13] | 7 Pin Header for BME280 and SCD30 | [https://www.digikey.com/en/products/detail/sullins-connector-solutions/PPTC071LFBN-RC/810146](https://www.digikey.com/en/products/detail/sullins-connector-solutions/PPTC071LFBN-RC/810146) |
| 12 Pin Headers | ![][image14] | 12 Pin Header for Feather Logger and M0 | [https://www.digikey.com/en/products/detail/sullins-connector-solutions/PPTC121LFBN-RC/807231](https://www.digikey.com/en/products/detail/sullins-connector-solutions/PPTC121LFBN-RC/807231) |
| 16 Pin Headers | ![][image15] | 16 Pin Header for Feather Logger and M0 | [https://www.digikey.com/en/products/detail/sullins-connector-solutions/PPTC161LFBN-RC/810154](https://www.digikey.com/en/products/detail/sullins-connector-solutions/PPTC161LFBN-RC/810154) |
| Feather Stacking Header Set | ![][image16] | Stacking header for Feather M0 | [https://www.adafruit.com/product/2830](https://www.adafruit.com/product/2830) |
| Grove Female Header \- DIP-4P-2.0mm | ![][image17] | i2c Grove Connector | [https://www.seeedstudio.com/Grove-Universal-4-pin-connector.html](https://www.seeedstudio.com/Grove-Universal-4-pin-connector.html) |
| CSL\_AQS\_V1 PCB Board (KiCAD) | ![][image18] | PCB Board | [https://www.pcbway.com/](https://www.pcbway.com/) [https://github.com/Community-Sensor-Lab/Air-Quality-Sensor/tree/CSL\_AQS\_V5](https://github.com/Community-Sensor-Lab/Air-Quality-Sensor/tree/CSL_AQS_V5) |
| PVC Tube | ![][image19] | PVC 3 Inch Diameter 7 Inch LengthTube | [https://www.homedepot.com/p/Charlotte-Pipe-3-in-x-2-ft-PVC-DWV-Sch-40-Pipe-PVC073000200HA/100533056](https://www.homedepot.com/p/Charlotte-Pipe-3-in-x-2-ft-PVC-DWV-Sch-40-Pipe-PVC073000200HA/100533056) |
| PVC Cap | ![][image20] | PVC Cap 3 Inch Diameter | [https://www.homedepot.com/p/3-in-PVC-DWV-Cap-PVC001161000HD/203393254](https://www.homedepot.com/p/3-in-PVC-DWV-Cap-PVC001161000HD/203393254) |
| Type C Cable | ![][image21] | Micro USB Cable | [https://www.amazon.com/Ruaeoda-Micro-Android-Charger-Gold-Plated/dp/B0D7RZJSPS/ref=sr\_1\_10?s=industrial\&sr=1-10](https://www.amazon.com/Ruaeoda-Micro-Android-Charger-Gold-Plated/dp/B0D7RZJSPS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)  |
| Grainger \#6 Screw | ![][image22] | 6-32 x 1/2'' Socket Head Screw | [https://www.mcmaster.com/catalog/130/3555/92196A146](https://www.mcmaster.com/catalog/130/3555/92196A146)  |
| Grainger \#6 Screw | ![][image23] | 6-32 x 1/2'' Phillip Head Screw | [https://a.co/d/00aQRtf8](https://a.co/d/00aQRtf8) |
| 6\#-32 Lock Nuts | ![][image24] | 6\#-32 Lock Nuts | [https://www.amazon.com/dp/B09V2SMKCS?ref=cm\_sw\_r\_cp\_ud\_dp\_85DV0K4XSP3YVNZTQ9CF\&ref\_=cm\_sw\_r\_cp\_ud\_dp\_85DV0K4XSP3YVNZTQ9CF\&social\_share=cm\_sw\_r\_cp\_ud\_dp\_85DV0K4XSP3YVNZTQ9CF\&skipTwisterOG=2\&th=1](https://www.amazon.com/dp/B09V2SMKCS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)  |
| 11mm, M2.5 Standoffs | ![][image25] | 100 Pcs M2.5 11mm Standoffs | [https://www.amazon.com/dp/B0BK99T8S4?\_encoding=UTF8\&psc=1\&ref=cm\_sw\_r\_cp\_ud\_dp\_NJHTWAXYMZAMQTEPGTWG\&ref\_=cm\_sw\_r\_cp\_ud\_dp\_NJHTWAXYMZAMQTEPGTWG\&social\_share=cm\_sw\_r\_cp\_ud\_dp\_NJHTWAXYMZAMQTEPGTWG\&skipTwisterOG=2](https://www.amazon.com/dp/B0BK99T8S4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)  |
| Hex Nuts, M2.5x0.45mm | ![][image26] | 100 Pcs M2.5x0.45mm Hex Nuts | [https://www.amazon.com/dp/B07H3WGLJN?\_encoding=UTF8\&psc=1\&ref=cm\_sw\_r\_cp\_ud\_dp\_YWEFJ3H8FVGTAFAJ55B1\&ref\_=cm\_sw\_r\_cp\_ud\_dp\_YWEFJ3H8FVGTAFAJ55B1\&social\_share=cm\_sw\_r\_cp\_ud\_dp\_YWEFJ3H8FVGTAFAJ55B1\&skipTwisterOG=2](https://www.amazon.com/dp/B07H3WGLJN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)  |
| M2.5x6mm Screws | ![][image27] | 100 Pcs M2.5x6mm Screws | [https://www.amazon.com/dp/B01B1PGR22?\_encoding=UTF8\&psc=1\&ref=cm\_sw\_r\_cp\_ud\_dp\_V3CT5FRAVAEGDJX2H49D\&ref\_=cm\_sw\_r\_cp\_ud\_dp\_V3CT5FRAVAEGDJX2H49D\&social\_share=cm\_sw\_r\_cp\_ud\_dp\_V3CT5FRAVAEGDJX2H49D\&skipTwisterOG=2](https://www.amazon.com/dp/B01B1PGR22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)  |

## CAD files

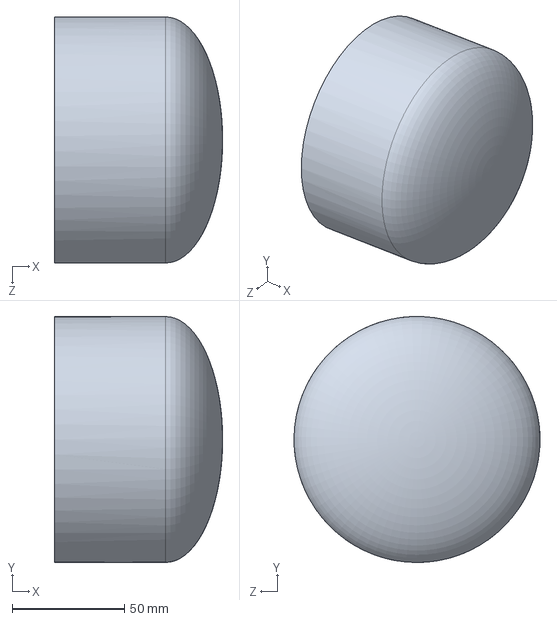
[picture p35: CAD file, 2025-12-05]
Contents/M_CAD-Inventor/3in End Cap/3in End Cap.SLDPRT
74.9 x 109.4 x 109.5 mm

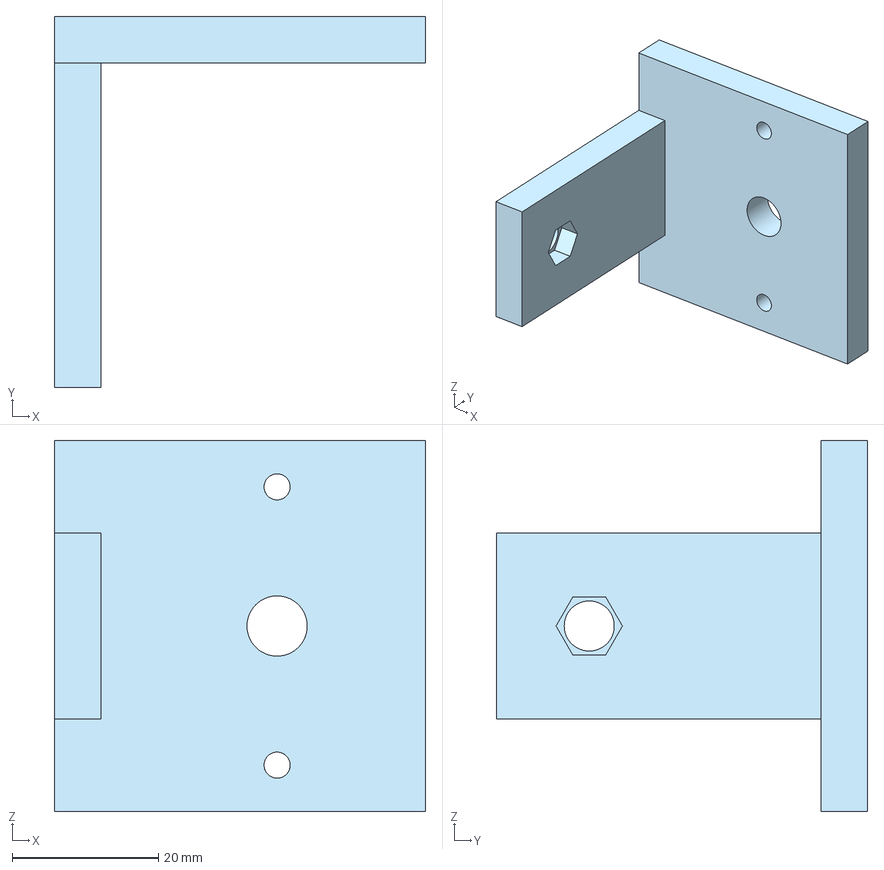
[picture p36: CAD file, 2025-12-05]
Contents/M_CAD-Inventor/Antenna/LBracket1.step
50.8 x 50.8 x 50.8 mm

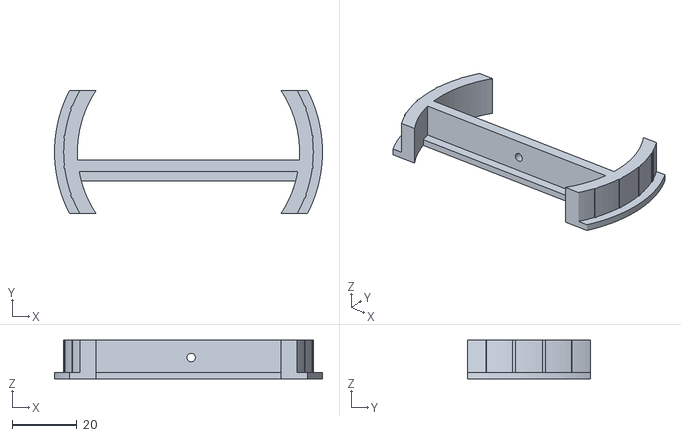
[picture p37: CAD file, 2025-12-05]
Contents/M_CAD-Inventor/AQS_Mount.stl
83.0 x 38.0 x 12.0

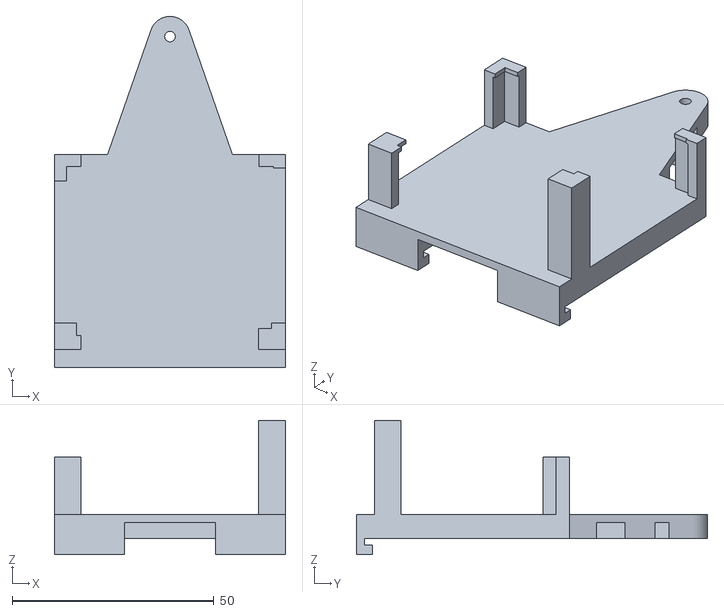
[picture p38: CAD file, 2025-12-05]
Contents/M_CAD-Inventor/Sensirion_STEP_SEN5x/SEN5X_Mount.stl
57.3 x 87.1 x 33.3

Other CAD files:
Contents/M_CAD-Inventor/3in End Cap/3in End Cap.ipt
Contents/M_CAD-Inventor/3in End Cap/OldVersions/3in End Cap.0002.ipt
Contents/M_CAD-Inventor/3in End Cap/PVC.ipt
Contents/M_CAD-Inventor/AQS Assembly.iam
Contents/M_CAD-Inventor/AQS_Mount.ipt
Contents/M_CAD-Inventor/Antenna/SEN5X Mount V4 Antena.ipt
Contents/M_CAD-Inventor/CSL_AQS_V1_spin3.iam
Contents/M_CAD-Inventor/Mount.ipt
Contents/M_CAD-Inventor/OldVersions/AQS Assembly Test.0004.iam
Contents/M_CAD-Inventor/OldVersions/AQS Assembly Test.iam
Contents/M_CAD-Inventor/OldVersions/AQS_Mount.0002.ipt
Contents/M_CAD-Inventor/OldVersions/AQS_Mount.0015.ipt
Contents/M_CAD-Inventor/OldVersions/AirQualitySensorMount.0008.ipt
Contents/M_CAD-Inventor/OldVersions/Assembly.0010.iam
Contents/M_CAD-Inventor/OldVersions/Assembly1.0006.iam
Contents/M_CAD-Inventor/OldVersions/CSL_AQS_V1_spin3.0002.iam
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

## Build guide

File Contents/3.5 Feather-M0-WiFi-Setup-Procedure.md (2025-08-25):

# Setup for a New Adafruit Feather M0 with WiFi (WINC1500)

This step is a one-time procedure for new, out of bag, [FeatherM0 WiFi boards](https://www.adafruit.com/product/3010) (Adafruit).

## ⚠️ Important Requirements

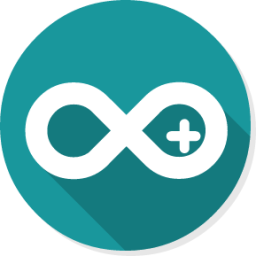
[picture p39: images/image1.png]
Arduino IDE V1.x
**NOTE: This procedure only works with the old Arduino IDE that has the round icon  **(V1.x)**

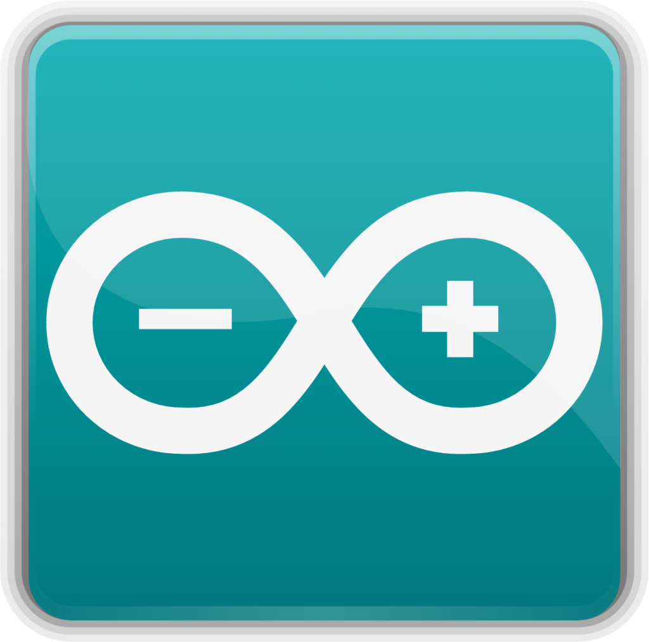
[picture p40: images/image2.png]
Arduino IDE V2.x
**It does not work on the new IDE with the square icon  **(V2.x)**

---

## Step-by-Step Setup Process

### 1. Prepare Your Development Environment

Open the old [Arduino IDE (V1.x)](https://www.arduino.cc/en/software/OldSoftwareReleases). If you don't have it installed, download and set it up. You can have both versions on your computer.

### 2. Install Required Libraries

Check that the latest [WiFi101 library](https://github.com/arduino-libraries/WiFi101) is installed. If not, install or update it through the Library Manager.

### 3. Load the Firmware Updater Sketch

Open the following arduino sketch: **Examples > WiFi101 > FirmwareUpdater**

### 4. Configure for Feather M0 WiFi

In the example, add the line of code shown below at line 43:

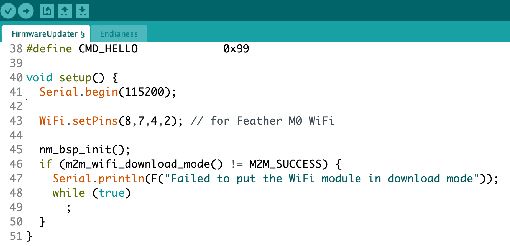
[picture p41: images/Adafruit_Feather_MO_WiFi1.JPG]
Code modification for Feather M0 WiFi


*This instruction sets the control pins in the program to work with the Feather M0 Wifi board*

### 5. Upload the Firmware Updater

Upload the code to your board. **Do not open the Serial Monitor.**

---

## Firmware Update Process

### 6. Open the Firmware Updater Tool

At the top of the Arduino IDE window, go to **Tools > WiFi101 / WiFiNINA Firmware Updater** as shown here:

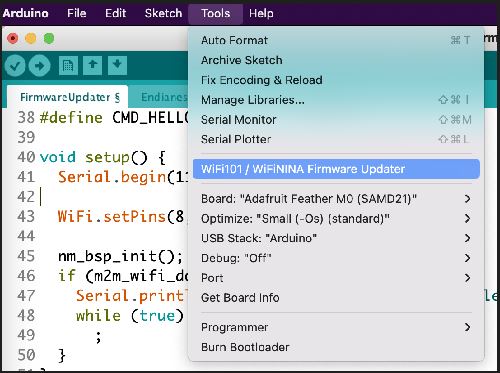
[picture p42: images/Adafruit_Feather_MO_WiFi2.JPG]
Accessing the firmware updater tool


You will get the following window:

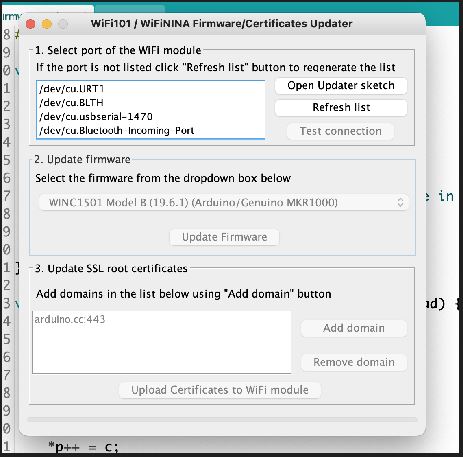
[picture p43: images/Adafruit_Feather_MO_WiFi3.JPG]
Firmware updater interface


### 7. Test Connection

Test the connection between your computer and the FeatherM0WiFi with **1. Select port of the WiFi module.**

### 8. Update Firmware

**2. Update Firmware.** Select the latest version of the [WINC1501 Model B](https://www.microchip.com/en-us/product/ATWINC1500) (19.6.1 in the picture above).

### 9. Configure SSL Certificates

**3. Update SSL root certificates.** 

- Select **Add domain**
- Enter [**www.google.com**](http://www.google.com)
- Repeat and enter **script.google.com** 

Your window should look like this:

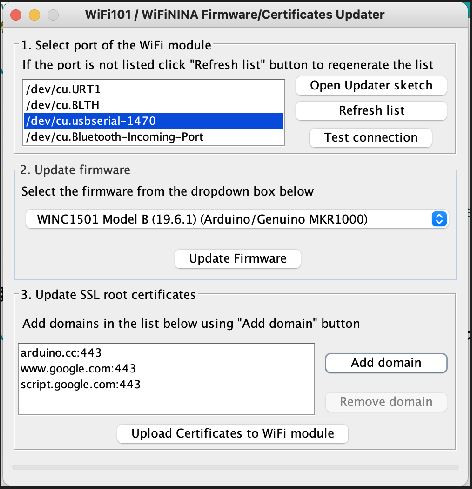
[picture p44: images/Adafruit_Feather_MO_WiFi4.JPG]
SSL certificate configuration


### 10. Complete the Setup

Select **Upload Certificates to WiFi module** and the Feather M0 WiFi board is ready for use with Google.

---

✅ ESP32 Provisioning Flowchart (Reference)
While this guide focuses on the Feather M0 WiFi board, many of the same principles apply to ESP32-based systems used in other CSL sensor builds. To help visualize the provisioning process—including WiFi setup, sensor initialization, and cloud integration—refer to the flowchart below:

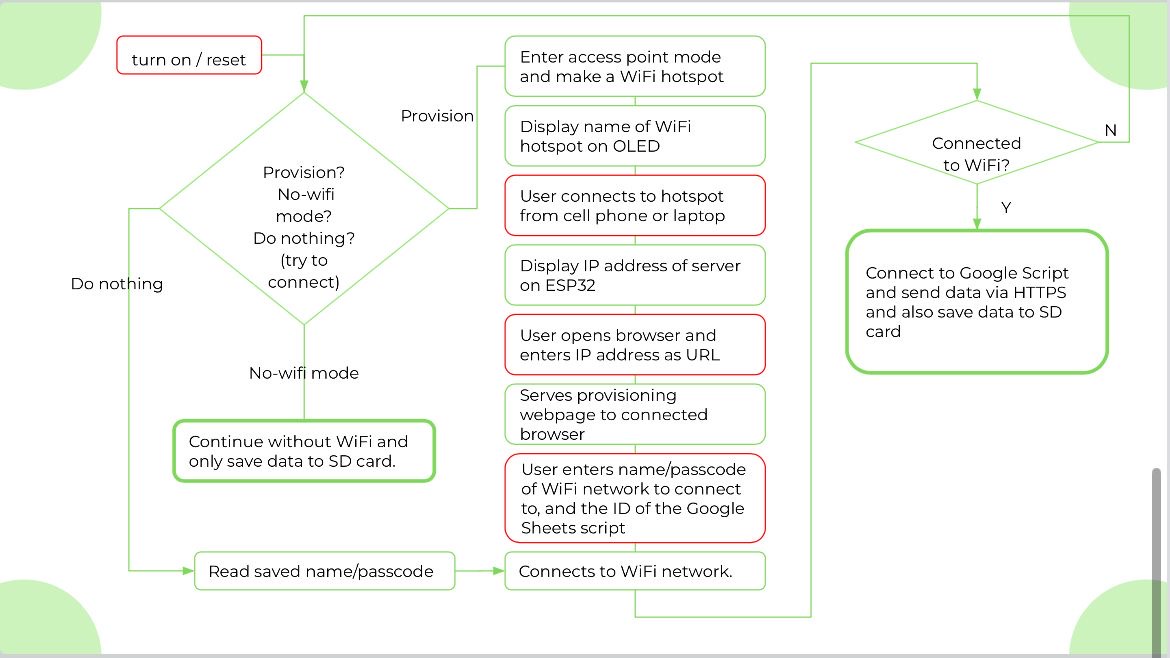
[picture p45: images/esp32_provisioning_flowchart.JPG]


This diagram outlines:

🔌 Hardware setup and boot sequence

📶 WiFi credential input and connection logic

🌡️ Sensor calibration and data logging

☁️ Optional cloud services integration

Use this as a reference when adapting firmware or onboarding new contributors working with ESP32 boards.

## Additional Resources

**More info at:** [Updating Firmware](https://learn.adafruit.com/adafruit-feather-m0-wifi-atwinc1500/updating-firmware)

## Troubleshooting

If you encounter issues during this process:
- Ensure you're using Arduino IDE V1.x (not V2.x)
- Verify the WiFi101 library is properly installed
- Check that your board is properly connected and recognized by your computer
- Make sure you don't have the Serial Monitor open during firmware upload

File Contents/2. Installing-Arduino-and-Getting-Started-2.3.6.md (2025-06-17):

**Installing Arduino**  
To get started, make sure the **Arduino application** is installed on your computer or laptop. If it hasn't been installed yet, visit the [Arduino website](https://www.arduino.cc/en/software/) to download and install it.  
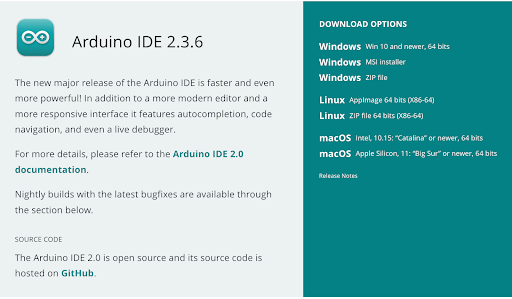
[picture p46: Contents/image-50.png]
Arduino IDE Download Page


# Arduino Download Instructions

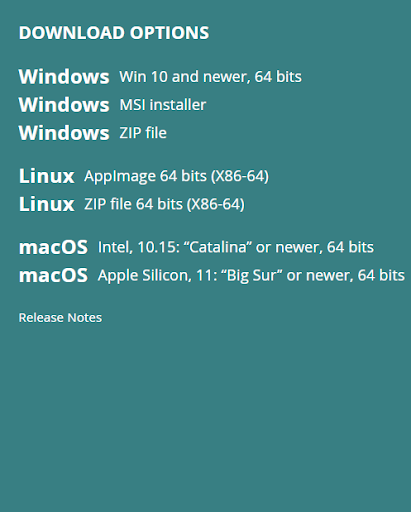
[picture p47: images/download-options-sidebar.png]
Arduino Download Options


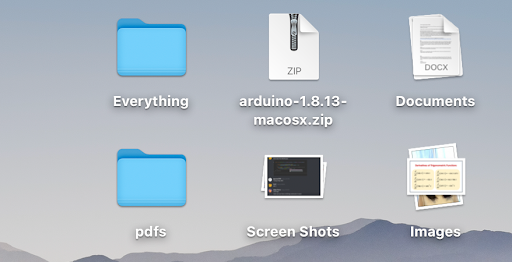
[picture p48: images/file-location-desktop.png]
Windows Download Options


On the Arduino download page, choose the version that matches your computer's operating system.

## For Windows users:

- **Do not** select the **.zip file** option.
- Instead, choose either **"Windows 64-bit App"** or **"Windows Installer"** for proper installation.

## After the download is complete:

- **On a Mac**: The zip file may appear on your **Desktop** or in your **Downloads** folder.
- **On Windows**: The zip file will typically be found in your **Downloads** folder or on your **Desktop**.

  **On a Mac**:

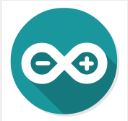
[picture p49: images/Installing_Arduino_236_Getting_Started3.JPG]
Mac Installation
  

* Open the downloaded zip file.  
* The Arduino application will appear—**drag it into your  Applications folder** to install it.

**On Windows**:

* Open the file you downloaded—either the **64-bit App** or the **MSI Installer**.  
* Follow the prompts to complete the installation.

---

**Arduino Environment**

Now that the Arduino application has been installed successfully, open it. The Arduino IDE should look something like this:

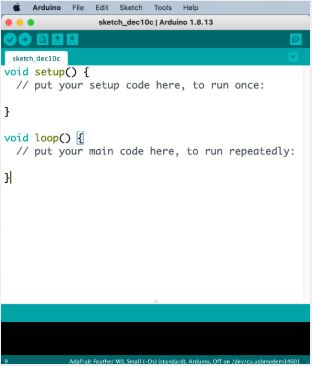
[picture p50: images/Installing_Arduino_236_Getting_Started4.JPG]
Arduino IDE Interface


- This is where the code is written to run Arduino programs
- Any error messages will appear **in the margins of the black console window** when you run your code

## Installing Required Packages and Libraries

Before running any programs on your **Arduino**, you must install a few essential packages and libraries. Without these, the Arduino won't be able to execute your code.

### Install Adafruit Board Package

This initial installation is required to give the Arduino application access to specific Adafruit libraries you'll need.

1. **Access Preferences**
   - Click on the Arduino drop-down menu and select Preferences (or Arduino → Settings)
   
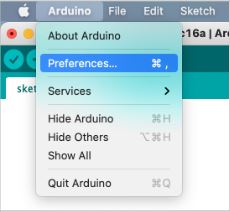
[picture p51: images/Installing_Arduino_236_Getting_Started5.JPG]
Arduino Preferences
   
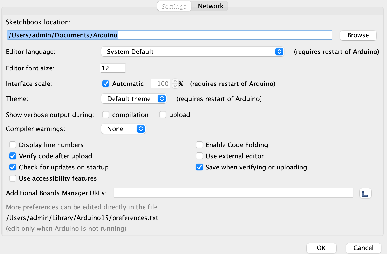
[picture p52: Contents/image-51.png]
Settings Menu
   

2. **Add Board Manager URL**
   - Copy this link: **https://adafruit.github.io/arduino-board-index/package_adafruit_index.json**
   - Paste the link in "Additional Boards Manager URLs"
   
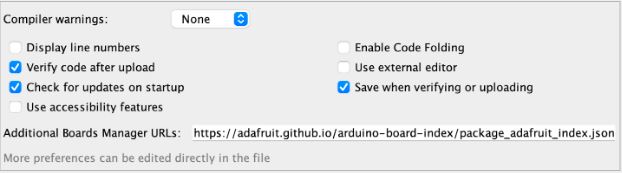
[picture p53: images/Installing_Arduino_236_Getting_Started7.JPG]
Board Manager URL
   

3. **Apply Settings**
   - Click "Ok" and close the Arduino Application

4. **Install Adafruit Boards**
   - Go to Tools → Board → Boards Manager
   
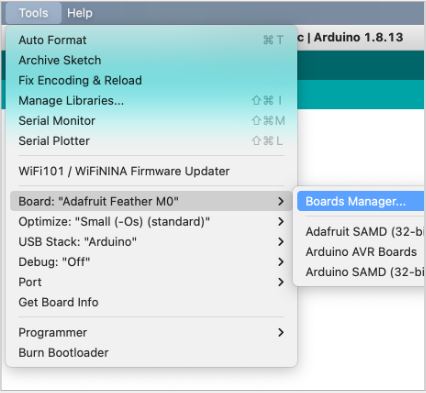
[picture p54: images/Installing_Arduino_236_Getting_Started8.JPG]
Boards Manager
   
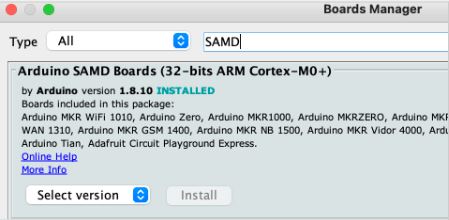
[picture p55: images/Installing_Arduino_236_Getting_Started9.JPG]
Boards Manager Window
   

5. **Close Boards Manager**
   - Once you are done downloading the necessary boards, close the Boards Manager window
   
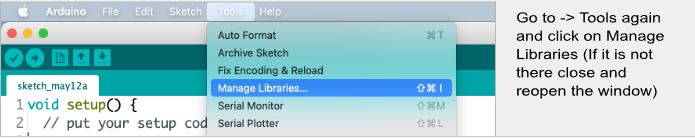
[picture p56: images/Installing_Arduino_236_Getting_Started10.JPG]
Close Boards Manager
   

### Install Required Libraries

1. **Access Library Manager**
   - Go to Tools → Manage Libraries

2. **Install WiFi101 Library**
   - In the search bar type "WiFi101" and install the library called "WiFi101"
   
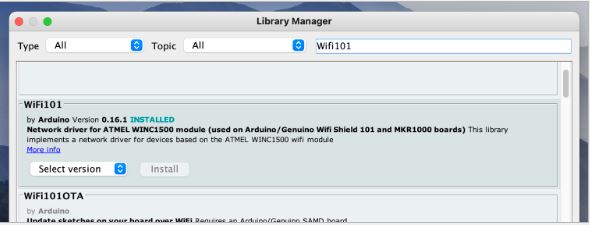
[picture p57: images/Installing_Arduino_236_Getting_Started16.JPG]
WiFi101 Library
   

3. **Install Additional Libraries**
   
   Repeat the search and install process for the following libraries (for libraries that require other libraries to be installed, click install all when prompted):

   - Adafruit Sleepy Dog
   - SparkFun SCD4X Arduino Library
   - Adafruit GFX
   - Adafruit SSD1306
   - Adafruit BME280
   - Adafruit SH110X
   - Sensirion I2C SEN5X
   - flashstorage
   - WiFi101
   - Honeywell TruStability SPI

4. **Install RTClib Library**
   - Download RTClib from [Github](https://github.com/adafruit/RTClib)
   - In Arduino IDE: Select Sketch → Include Library → Add .ZIP Library
   - Open the ZIP folder that you have just downloaded

**Installation Complete!** You now have all the necessary components installed.

---

## Connecting and Testing Your Arduino

### Hardware Connection

1. **Connect Arduino to Computer**
   - Plug in your Arduino to your laptop using a Micro-USB Cable
   - If you do not have a USB port on your computer, you will need an adapter
   
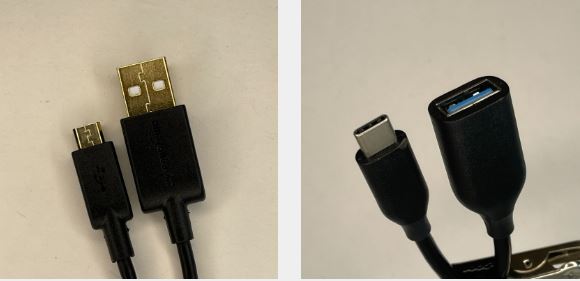
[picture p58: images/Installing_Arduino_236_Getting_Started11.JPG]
Arduino Connection
   

### Software Configuration

2. **Select the Correct Port**
   - Launch Arduino IDE and select the correct port with the dropdown menu
   
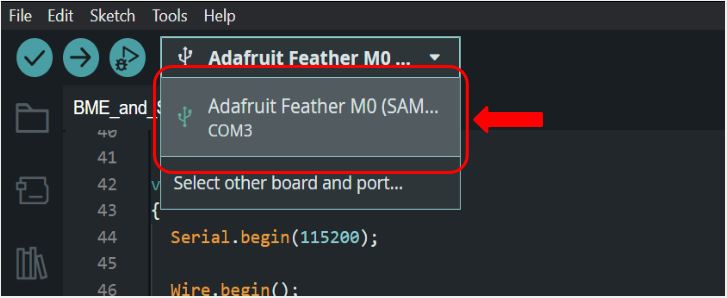
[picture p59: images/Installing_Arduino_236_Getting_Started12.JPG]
Port Selection
   

### Code Compilation and Upload

3. **Compile Your Code**
   - When you have the correct port selected and you are ready to compile code to your Arduino, first compile the code to check for any errors beforehand
   
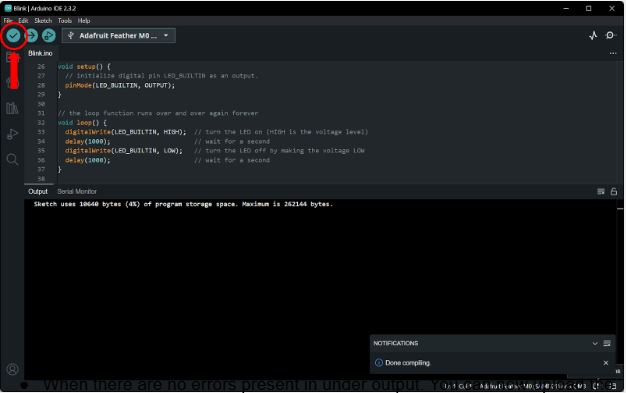
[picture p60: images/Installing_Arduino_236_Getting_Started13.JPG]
Compile Code
   

4. **Upload to Arduino**
   - When there are no errors present in the output, you can now upload the code to your Arduino
   
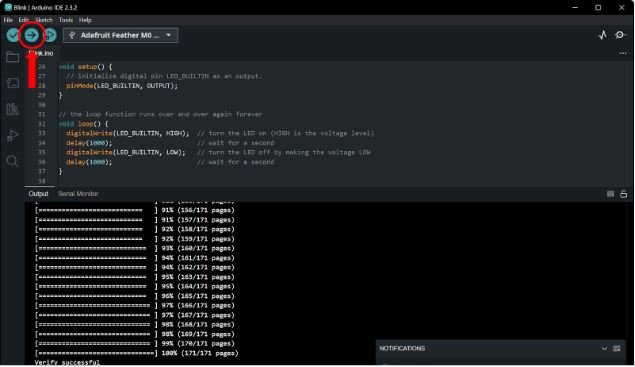
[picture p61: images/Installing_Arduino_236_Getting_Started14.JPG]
Upload Code
   

## Testing Your Setup

### Running the Blink Example

Now that you have all the libraries downloaded, you can test the connection between the sensor and your computer.

1. **Load Blink Example**
   - Go to File → Examples → Basics → Blink to pull up the blink code
   - This code can be used to test if the sensor is connected to your computer and can have code uploaded to it
   
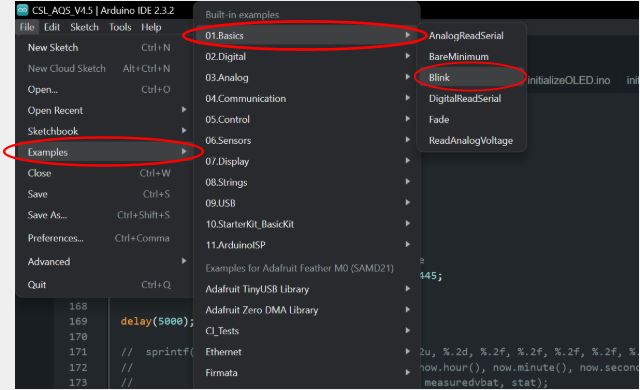
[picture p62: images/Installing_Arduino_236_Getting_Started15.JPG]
Blink Example
   

2. **Test the Connection**
   - Upload the code and look at the sensor when the code finishes uploading
   - Check if the light is blinking to confirm successful connection

---

## Troubleshooting

If you encounter issues:
- Ensure the correct port is selected
- Check that all required libraries are properly installed
- Verify your Arduino is properly connected via USB
- Review any error messages in the console window for specific guidance

Your Arduino setup is now complete and ready for sensor projects!

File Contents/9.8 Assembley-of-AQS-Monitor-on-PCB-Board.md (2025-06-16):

# Assembly of Air Quality Monitor Components on a PCB Board

## Materials:

- PCB board
- [Feather M0 WiFi (WINC1500)](https://www.adafruit.com/product/3010) Microcontroller and WiFi Radio
- [Featherwing Logger (RTC microSD)](https://www.adafruit.com/product/2922) Real-time Clock and MicroSD Reader
- [Featherwing OLED 128x64](https://www.adafruit.com/product/2900) Display Screen
- [Adafruit SCD41 CO2 Sensor](https://www.adafruit.com/product/5190)
- [BME280 Temp. Press. Rel Humidity Sensor](https://www.adafruit.com/product/2652)
- [Sensirion SEK-SEN5X](https://www.sensirion.com/products/catalog/SEK-SEN5X/) Particulate Matter/VOC/NOX Sensor
- [MiniBoost 5V](https://www.adafruit.com/product/4654)
- Standoff Screws with Hex Nuts and Cap Screw Bolt
- Battery Pack

## Tools:

- [H 1.5 Screwdriver](https://www.adafruit.com/product/3790)

## Assembly STEPS

1. Place the PCB in the same orientation as the Photo.

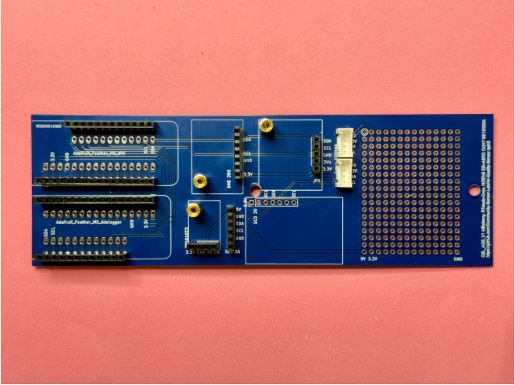
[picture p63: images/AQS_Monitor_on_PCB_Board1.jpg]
PCB Board Orientation


---

## Step I. Connect the Feather M0 WiFi (WINC1500)

1. **Locate the Feather M0 WiFi:**
   - Notice that the PCB board's label, "Feather M0 WiFi," is printed on the upper left-hand side.

2. **Align the Feather M0 WiFi:**
   - Before making any connections, carefully align the header pins directly above the female sockets on the PCB. Double-check to ensure that all pins are correctly positioned over the corresponding sockets.

3. **Position and Check Alignment:**
   - Ensure that the pins are directly about the socket and are evenly aligned before pressing them into place. Any misalignment could cause the pins to bend or damage them.

4. **Gently Insert the Pins:**
   - With the pins aligned, gently press the Feather M0 WiFi into the sockets. Apply light pressure, and if necessary, gently wiggle the board slightly to help the pins slide smoothly into the sockets.

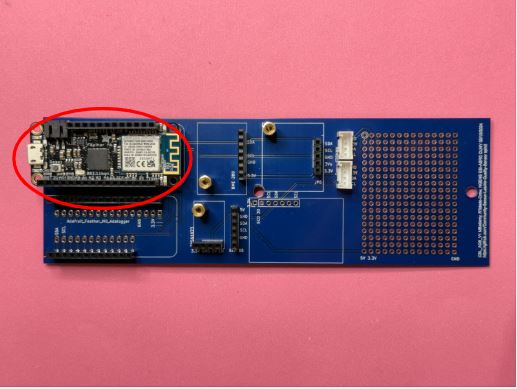
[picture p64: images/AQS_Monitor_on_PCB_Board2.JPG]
PCB Board Orientation


**Note:** The Feather M0 WiFi (WINC1500) is equivalent to a computer's central processing unit (CPU).

---

## Step II. Connect the Featherwing Logger (RTC MicroSD)

1. **Locate the Feather M0 Adalogger:**
   - Notice that the PCB board's label, "Feather M0 Adalogger," is printed on the bottom left-hand side.
   - Follow the same installation techniques and instructions above.

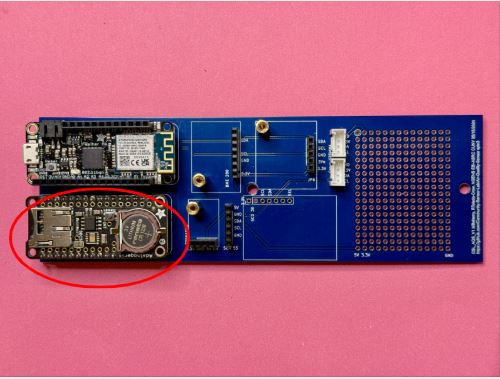
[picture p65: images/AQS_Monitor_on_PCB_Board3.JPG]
PCB Board Orientation


**Note:** The Featherwing M0 AdaLogger is equivalent to a computer's memory and data storage.

---

## Step III. Connect the BME280 Temp. Pressure Relative Humidity Sensor

1. **Locate the [BME280](https://www.bosch-sensortec.com/products/environmental-sensors/humidity-sensors-bme280/) Temp. Pressure, and Humidity Sensor:**
   - This sensor has seven pins. Locate the label 'BME280' printed on the board.
   - Connect the BME280 sensor by inserting the pins in the 7-pin socket.

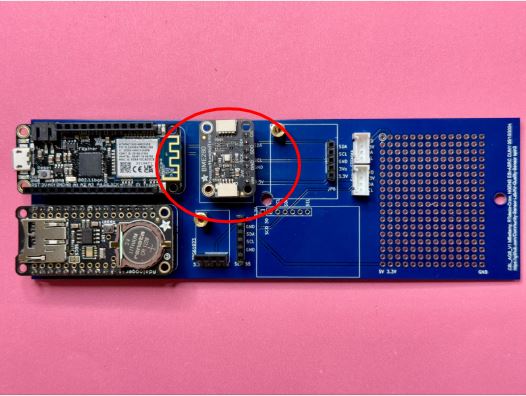
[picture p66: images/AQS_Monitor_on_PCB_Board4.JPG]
PCB Board Orientation

---

## Step IV. Connect the MiniBoost 5V - 3.3 to 5V (Voltage) Converter

1. **Locate the MiniBoost 5V - 3.3 to 5V Voltage Converter:**
   - Connect the MiniBoost 5V directly below the BME280 sensor.
   - Insert the four pins in the sockets labeled: 3V, GND, 5V, and EN.

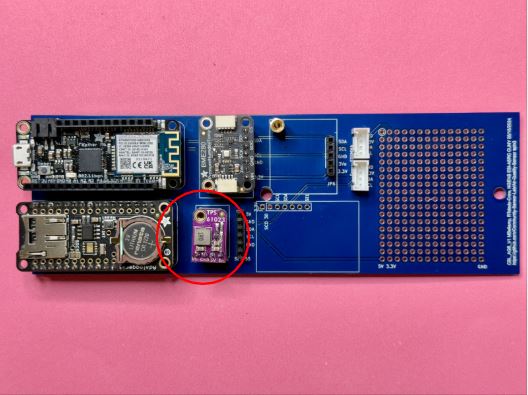
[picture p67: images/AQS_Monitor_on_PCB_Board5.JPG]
PCB Board Orientation


---

## Step V. Connect the Adafruit SCD41 CO2 Sensor

1. **Locate the SCD41 CO2 Sensor:**
   - Locate the label 'SCD' printed on the board.
   - Connect the SCD41 CO2 Sensor to the right of the BME280 sensor.
   - Insert the five pins into the sockets labeled SDA, SCL, GND, 3V0, and 3.3V.

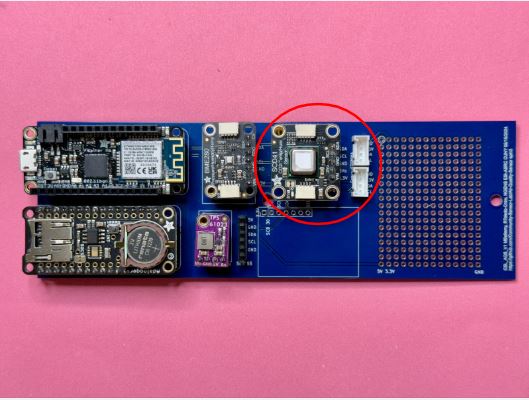
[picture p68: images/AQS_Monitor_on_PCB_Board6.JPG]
PCB Board Orientation

---

## Step VI. Connect the Featherwing OLED 128x64 Display Screen

1. **Locate the OLED Display Screen:**
   - Locate the OLED Display Screen.
   - Connect the OLED Display to the Feather M0 WiFi.
   - Align the pins and press gently until they are completely inserted and no longer visible.

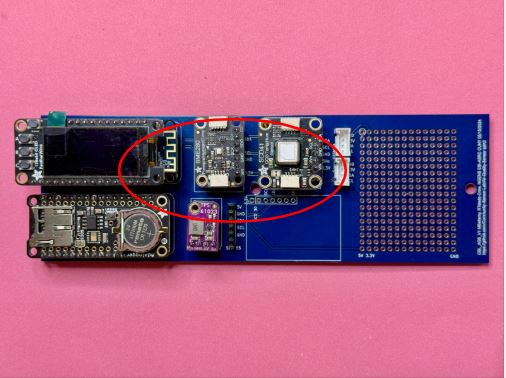
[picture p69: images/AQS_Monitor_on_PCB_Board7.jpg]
PCB Board Orientation


**Note:** The OLED Display is equivalent to a computer screen.

---

## Step VII. Connect the Sensirion SEK-SEN5X Particulate Matter/VOC/NOX Sensor

1. **Locate the Sensirion SEK-SEN5X Particulate Matter/VOC/NOX Sensor:**
   - The sensor has six color-coded wires connected to pins.
   - On the board to the right of the MiniBoost 5V 3.3 to 5V Voltage Converter, locate the six sockets labeled 5V, GND, SDA, SCL, and GND.
   - Align the pins starting with the labeled red 5V wire, and align it with the 5V socket.
   - Carefully locate the corresponding sockets for each color-coded wire from the sensor.
   - The last wire, colored purple, should be connected to the previous socket labeled GND.
   - Connect the wires to the corresponding sockets, making sure the pins are no longer visible.
   - Align the pins and press gently until they are completely inserted and no longer visible.

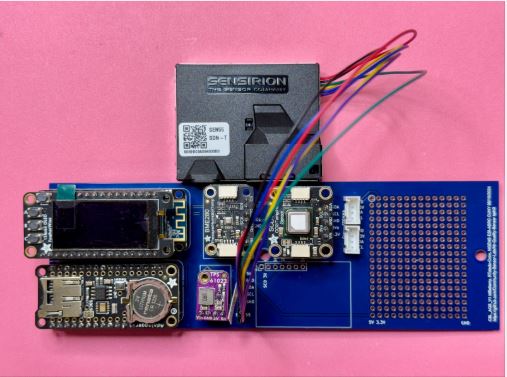
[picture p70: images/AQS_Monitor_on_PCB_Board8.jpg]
PCB Board Orientation


---

## Final Assembly Notes

### Power Connection
- Connect your battery pack to provide power to the entire system
- The MiniBoost 5V converter will regulate power distribution to components requiring different voltages

### Testing
- Once all components are installed, power on the system
- The OLED display should show initialization messages
- Verify all sensors are detected and providing readings

### Troubleshooting
- If components are not detected, check all connections are secure
- Ensure pins are fully inserted into their sockets
- Verify correct alignment of all components

## Next Steps

After successful assembly, you'll need to:
1. Install the appropriate firmware
2. Configure WiFi settings for data transmission
3. Set up data logging and monitoring
4. Calibrate sensors if required

Your air quality monitor is now ready to help track environmental conditions and contribute to community air quality awareness!

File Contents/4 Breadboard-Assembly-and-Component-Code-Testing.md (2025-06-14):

# How to Assemble Air Quality Sensor Boards

This guide walks you through assembling your air quality sensor, focusing on attaching the boards onto the breadboard and testing each component systematically. Make sure that sensors and boards (with the exception of the SPS30 PM 2.5 Sensor) are soldered to the appropriate headers.

## 📋 Materials Required

**Note:** Refer to the complete [Parts List](https://github.com/Community-Sensor-Lab/Air-Quality-Sensor/blob/master/README.md#Parts-List-) on GitHub for detailed specifications.

### Essential Components:
- [Breadboard](https://www.adafruit.com/product/239) 
- Soldered CPU & WiFi Board ([Adafruit Feather M0](https://www.adafruit.com/product/3010))
- Soldered OLED Display Board
- Soldered Logger & Clock Board ([Adalogger FeatherWing](https://www.adafruit.com/product/2922))
- [Coin Battery CR1220](https://www.adafruit.com/product/380)
- [SD card](https://www.adafruit.com/product/1294) (formatted)
- [Micro-USB to USB cable](https://www.adafruit.com/product/592) (or alternatively, a battery pack)
- Jumper Wires ([Premium Male/Male](https://www.adafruit.com/product/758))

### Sensors:
- Soldered [BME 280](https://www.adafruit.com/product/2652) (Temperature, Humidity, Pressure)
- Soldered [SCD41](https://www.adafruit.com/product/5190) (CO2)
- [SEN55](https://www.sensirion.com/products/catalog/SEN55/) (All-in-one environmental sensor)

### Tools Needed:
- Computer with Arduino IDE installed
- [SD Card Reader](https://www.adafruit.com/product/939) (if not built into computer)
- [SD Card Formatter](https://www.sdcard.org/downloads/formatter/) software

---

## 🚀 Getting Started

### Initial Setup

1. **Prepare your workspace:** Have a clear breadboard in front of you. This will be your main assembly platform.

2. **Organize components:** Keep your FeatherM0 CPU & WiFi board nearby - this is the central hub that all sensors will connect to.

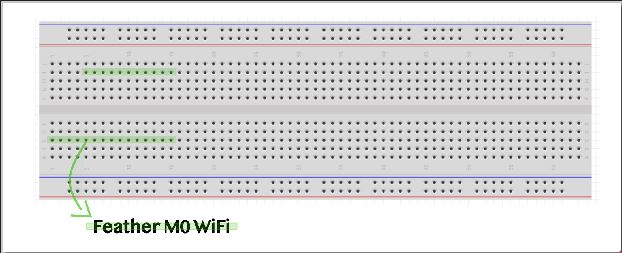
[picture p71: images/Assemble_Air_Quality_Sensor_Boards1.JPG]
breadboard setup


---

## ⚙️ Preliminary Configuration

### Setting Time and Date on Arduino Real Time Clock (RTC)

**Important:** Complete this step before assembling sensors to ensure accurate timestamping.

1. **Install Adalogger:** Insert Adalogger on top of the Feather M0
2. **Open RTC example code:** 
   - Navigate to Examples → RTCLib → Open pcf8523
3. **Modify the code:** Comment out lines 21, 22, and 34 (add `//` at the beginning of each line)

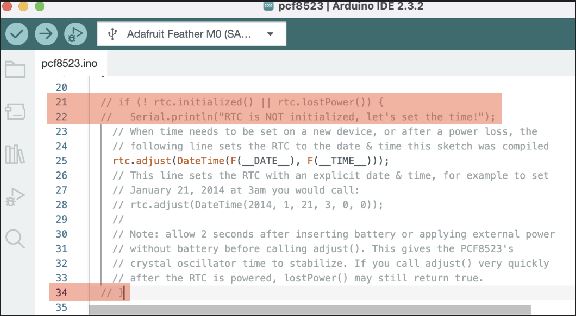
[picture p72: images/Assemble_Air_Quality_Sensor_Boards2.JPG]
RTC Setup


4. **Upload the code:**
   - Select correct board: Tools → Board → Adafruit SAMD boards → Adafruit Feather M0
   - Select correct port: Tools → Port → Select the one with sensor
   - Click Upload

5. **⚠️ Critical:** DO NOT RESET/RESTART THE ARDUINO after uploading as this will reset the clock to compilation time. Instead, proceed directly to upload the main AQI code.

### SD Card Preparation

1. **Download formatter:** Get the official SD card formatter from [https://www.sdcard.org/downloads/formatter/](https://www.sdcard.org/downloads/formatter/)

2. **Format the card:** 
   - Connect SD card to computer (use SD card reader if necessary)
   - Open SD card formatter application
   - Format using recommended settings

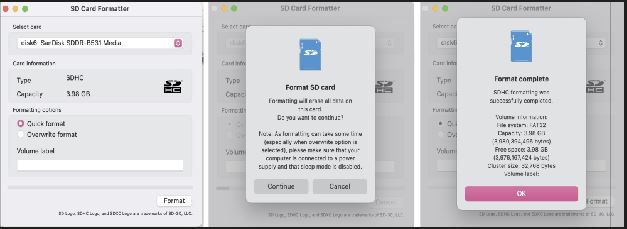
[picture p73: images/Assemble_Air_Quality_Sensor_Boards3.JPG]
SD Card Formatting


---

## 🔧 Sensor Assembly & Testing

**Assembly Strategy:** We'll add and test each sensor individually to ensure proper functionality before final assembly.

### 1. BME 280 Environmental Sensor

**📖 Reference:** [BME280 Datasheet](https://cdn-learn.adafruit.com/downloads/pdf/adafruit-bme280-humidity-barometric-pressure-temperature-sensor-breakout.pdf)

**Function:** Measures temperature, barometric pressure, and humidity.

#### Placement & Wiring

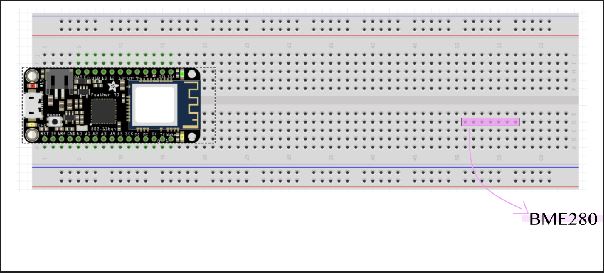
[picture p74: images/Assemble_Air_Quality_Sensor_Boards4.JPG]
BME280 Placement


**Wiring Guidelines:**
- **Power:** Voltage connects to red line (+), ground connects to blue line (-)
- Follow the color coding in the image below for accurate connections

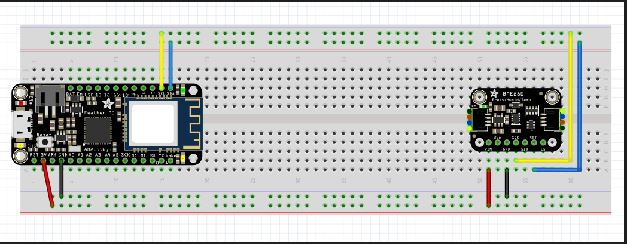
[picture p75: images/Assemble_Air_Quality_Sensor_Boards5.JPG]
BME280 Wiring


**Connection Map:**
- SCK/SCL → Top row of breadboard
- SDI/SDA → Second row of breadboard  
- VIN/3V → Last row of breadboard
- GND → Second to last row of breadboard

#### Testing BME280

1. **Load test code:** Open Examples → BME280 test

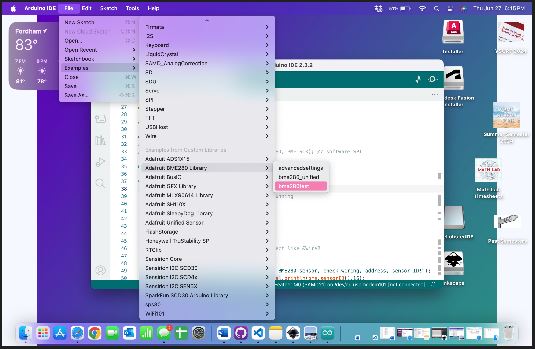
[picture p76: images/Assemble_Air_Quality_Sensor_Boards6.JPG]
BME280 Code


2. **Add debugging code:** After `void setup()` and `Serial.begin();`, add:
   ```arduino
   delay(5000);
   Serial.println(__FILE__);
   ```
   This ensures you can verify successful code execution.

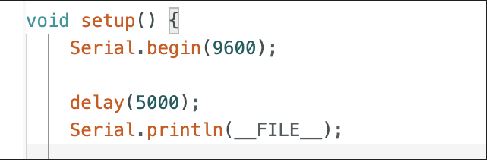
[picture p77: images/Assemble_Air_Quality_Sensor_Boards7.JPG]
BME280 Debug Code


3. **Upload and test:**
   - Connect board with USB data cable
   - Select board and port
   - Verify and upload code
   - Open Serial Monitor to view results
   - **Disconnect USB** before proceeding to next sensor

### 2. SCD41 CO2 Sensor  

**📖 Reference:** [SCD-40 and SCD-41 Datasheet](https://cdn-learn.adafruit.com/downloads/pdf/adafruit-scd-40-and-scd-41.pdf)

**Function:** Photoacoustic CO2 sensor measuring CO2 concentration in PPM (parts per million).

#### Placement & Wiring

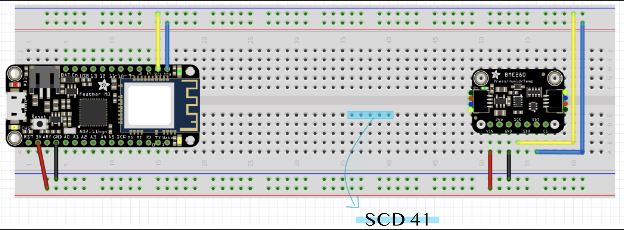
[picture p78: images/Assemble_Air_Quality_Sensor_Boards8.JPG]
SCD41 Placement


**⚠️ Important:** Keep the BME 280 connected when adding SCD41 - it provides necessary pull-up resistors. Alternatively, you can use the OLED display which also has pull-up resistors.

#### Testing SCD41

1. **Load test code:** Examples → Sparkfun SCD4x Arduino Library → Example8_SCD41SingleShot

SCD41 Code Selection

2. **Modify settings:** 
   - Change line 35 to `false false false`

SCD41 Code Modification

   - Comment out lines 76-92

SCD41 Code Comments

3. **Test:** Follow the same upload and testing procedure as BME 280
4. **Disconnect USB** before proceeding

### 3. SEN55 All-in-One Environmental Sensor

**📖 Reference:** [SEN5x Datasheet](https://sensirion.com/media/documents/6791EFA0/62A1F68F/Sensirion_Datasheet_Environmental_Node_SEN5x.pdf)

**Function:** Comprehensive sensor measuring:
- Particulate matter (PM1.0, PM2.5, PM4.0, PM10)
- Volatile organic compounds (VOCs)
- Humidity and temperature
- Oxidizing gases (NOx)

#### Placement & Wiring

SEN55 Placement

**Note:** Keep BME 280 connected for pull-up resistors (or use OLED display as alternative).

SEN55 Wiring

#### Testing SEN55

1. **Load test code:** Examples → Sensirion I2C SEN5x → exampleusage
2. **Test:** Follow the same upload and testing procedure as previous sensors
3. **Disconnect USB** before final assembly

SEN55 Testing

---

## 🎯 Final Assembly

Once all individual sensors have been tested successfully, assemble all components together on the breadboard as shown:

Final Assembly

**Final Steps:**
1. Carefully arrange all components according to the layout
2. Double-check all connections match the individual sensor wiring
3. Ensure no loose connections
4. Upload your main AQI monitoring code
5. Test the complete system

---

## 📚 Additional Resources

- [Community Sensor Lab GitHub Repository](https://github.com/Community-Sensor-Lab/Air-Quality-Sensor)
- [Arduino IDE Download](https://www.arduino.cc/en/software)
- [Adafruit Learning System](https://learn.adafruit.com/)

---

## ⚠️ Safety & Best Practices

- Always disconnect USB power before modifying wiring
- Double-check connections before powering on
- Handle sensors gently to avoid damage
- Keep workspace organized and well-lit
- Test each component individually before final assembly

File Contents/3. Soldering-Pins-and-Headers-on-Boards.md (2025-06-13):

# Component Soldering

## Materials

* Breadboard  
* [BME 280](https://www.adafruit.com/product/2652) - Temperature, humidity & pressure sensor with high accuracy
* [SCD 41](https://learn.adafruit.com/adafruit-scd-40-and-scd-41) - Photoacoustic 'true' CO2 sensor that measures CO2 PPM composition
* 5V Booster  
* SEN55  
* JST Cables  
* Featherwing OLED  
* Featherboard M0 WIFI  
* Adalogger Featherwing  
* Two Feather Stacking Headers Set  
* Micro SD  
* Coin Battery (cr1220)


*All components laid out for inventory check*

## Tools

* [Soldering Iron](https://www.adafruit.com/category/84) - Temperature-controlled recommended for precision work
* Soldering Wire  
* Wet Sponge  
* [Brass Wire Wool](https://www.adafruit.com/product/1172) - For cleaning soldering iron tip
* Fan/Exhaust  
* [Magnifier](https://www.adafruit.com/product/291) - Helps with precision component placement
* Riser Trimming Tool  
* Clipping Tool

## Step 1: Soldering SCD 41, BME 280, 5V Booster, and Featherwing OLED

* Place pin headers evenly spaced out onto the breadboard.  
* Place each sensor board onto the respective pins:  
  * **OLED**: When connecting the OLED to the breadboard, it can't be pushed all the way because pin headers stick out. This allows the OLED to lay perfectly on the black part of the pinheads.

   


* Make sure the [SCD41](https://www.bosch-sensortec.com/products/environmental-sensors/humidity-sensors-bme280/), [BME280](https://learn.adafruit.com/adafruit-scd-40-and-scd-41), and 5V Booster are connected straight on the breadboard.   
  * This can be accomplished by soldering one pin at one end and then applying the heat to move it in place with your other hand.  
  * You can also balance it before soldering by pushing it down with one finger on the pin side to keep it straight.  
* Once you have it straightened properly, complete the soldering for each pin.

## Step 2: Soldering Feather M0 Stacking Header and Logger Stacking Header

* For this part, have your OLED in hand, for it will make it easier to solder.  
* Attach a set of stacking headers to the OLED, then place the Adalogger Featherwing on top faced down.




* Now start by soldering one end at a time.



* Repeat the same steps for the Featherboard M0 WiFi.

## Step 3: Trimming the Stacking Headers

* Place the Riser Trimming tool in between the stacking headers.




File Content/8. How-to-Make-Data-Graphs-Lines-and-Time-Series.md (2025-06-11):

**Creating Charts with the Spreadsheet**

**Step I.** Use this Template[Walkshop-data](https://docs.google.com/spreadsheets/d/1RFhmyqTI_-M0KqMQCdK-JjGWuWDufaKyo__DD6yt2HA/edit?usp=sharing)

**Step II.** To select all data, follow the instructions below:

* Place the **cursor on Row 3, Column A**.   
  * To **Select** all Data on Google Sheets on a Mac: **Press Ctrl \+ Shift,**   
  * Now press the **↓Down Arrow** while still **pressing the Ctrl \+ Shift** (this will highlight selecting all the data in column A.    
  * To select the data across all Rows and Columns, **press the → Right Arrow**. Now, all of the data across the spreadsheet should be highlighted.  
  * For Mac, with the cursor on  

**Step III.** To create the graph, Go to **Insert** and select **Chart** from the drop-down menu.

* A chart should pop up on top of your datasheet. 

**Step IV:** Click on the **three dots** at the top right corner of the chart and Select “**Move to own Sheet**.” This allows you to move a chart from its current location, embedded within a sheet, to a separate, dedicated new sheet.

**Chart Editor:** The Chart Editor allows users to create, customize, and modify charts or graphs based on the data within the spreadsheet.

**Step VI.** A new sheet tab is created at the bottom of your Google Sheets file.                                                                                                         
Click on the **down arrow** and select **rename**   
to give the sheet a new name. 

**Step VII.** Click **Edit Chart** to open the Chart editor, which will appear on the right side of the screen.

**Step VIII: Label X-Axis using the Chart Editor**

* Click “**Add X-axis**” in the Chart editor and select **Google Datatime**.

**Google Datetime** allows you to format and represent date and time data on charts, making it easier to visualize trends over specific periods.

**Step VIII: Remove Series**

* In this section of the **Chart Editor**, you will remove 

Next remove Google Datetime,   
Series Datetime, V, status and any other   
series you may not want to put in this   
particular graph.

Change the chart type under set up into a line chart and it should look like this



**Creating a Timeline Chart**

To make a timeline chart click timeline chart under chart type



Be sure to have the following boxes selected:

Press the cell boxes under Data range and select the data ranges from your data sheet (Sheet1) that you would like to include in the timeline chart.

Your graph should now look like this (depending on the range cells you selected):  
\[In my case I selected all of A and C to H for: CO2, temp, humidity and pressure.\]



**Customize Data Lines**

Under the chart editor you can also customize the chart by changing the fill opacity or the line thickness using the drop down menu.



[image1]: <>

[image2]: <>

[image3]: <>

[image4]: <>

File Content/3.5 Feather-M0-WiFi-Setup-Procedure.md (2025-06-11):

**Setup for a new Adafruit Feather M0 with WiFi (WINC1500)**

This step is a one-time procedure for new, out of bag, FeatherM0 WiFi boards (Adafruit). 

**NOTE: This procedure only works with the old Arduino IDE that has the round icon(V1.x)**   
**It does not work on the new IDE with the square icon (V2.x)** 

1- Open the old Arduino IDE (V1.x) If you don’t have it installed, download and set it up. You can have both versions on your computer.

2- Check that the latest WiFi101 library is installed. If not, install or update it.

3- Open the following arduino sketch: **Examples \> WiFi101 \> FirmwareUpdater**

4- In the example, add the line of code shown below at lines 43:



This instruction sets the control pins in the program to work with the Feather M0 Wifi board

5- Upload the code. Do not open the Serial Monitor.

6- At the top of the Arduino IDE window, go to **Tools \> WiFi101 / WiFiNINA Firmware Updater** as shown here:



You will get the following window:



7- Test the connection between your computer and the FeatherM0WiFi with **1\. Select port of the WiFi module.**

8- **2\. Update Firmware.** Select the latest version of the WINC1501 Model B (19.6.1 in the picture above).

9- **3\. Update SSL root certificates.** Select **Add domain.** Enter [**www.google.com**](http://www.google.com) . Repeat and enter **script.google.com** so that your window is like this:



10- Select **Upload Certificates to WiFi module** and the Feather M0 WiFi board is ready for use with Google.

**More info at (** [Updating Firmware](https://learn.adafruit.com/adafruit-feather-m0-wifi-atwinc1500/updating-firmware) )  

[image1]: <>

[image2]: <>

[image3]: <>

[image4]: <>

[image5]: <>

[image6]: <>

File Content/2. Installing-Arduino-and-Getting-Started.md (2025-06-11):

**Installing Arduino**  
To begin, you must have the application Arduino installed on your pc or laptop. To install the application visit [Arduino](https://www.arduino.cc/en/software).
Installing Arduino

             Once you reach the download page, select the  
             download option that works for your computer.   
  If you are using Windows, **DO NOT** download it as   
  a zip file. Select either the **Windows 64 Bit App** or  
  **Windows installer**. 

 Once the download is complete, a zip file may appear on your computer if you are using a Mac  
or in the downloads folder if you are on Windows (most likely found in the Downloads folder or Desktop) 

On Mac \- Open the zip file and the Arduino application should appear then drag it into the Applications Folder

On Windows \- Launch either the 64 Bits Application or the MSI Installer continue with the install

---

**Arduino Environment**

Now that the Arduino application has been successfully installed, open the application. The Arduino IDE should look ← something like this.

← This is where the code is written to run Arduino programs.

← Any error messages will appear   
here once you run your code. 

---

**Installing Adafruit Packages and Libraries**

Before you can run any programs on the Arduino you will need to install a few packages and libraries. Without these installations, your Arduino will not be able to run any programs. 

**This first installation is necessary for the Arduino application to have access to some of the Adafruit libraries that you will need.** 

To install this package you need to copy this link   **↓**

### **https://adafruit.github.io/arduino-board-index/package\_adafruit\_index.json**

Once the link has been copied, go to the Arduino application on your laptop/pc and click on Arduino \-\>Settings

Paste the link you copied in “Additional Boards Manager URLs”

Click “Ok” and close the Arduino Application

Next, you will need to go to Tools \-\> Board \-\> Boards Manager

Now that you are done downloading the necessary boards on Boards Manager, close the Boards Manager window. 

In the search bar type “Wifi 101” and install the library called “Wifi 101”

Installing Arduino

Repeat this step with the following libraries (For libraries that require other libraries to be installed, click install all when prompted):

* Adafruit Sleepy Dog   
* SparkFun SCD4X Arduino Library  
* Adafruit GFX  
* Adafruit SSD1306  
* Adafruit BME280  
* Adafruit SH110X  
* Adafruit BusIO  
* Sensirion I2C SEN5X  
* flashstorage  
* WIFI 101  
    
* Honeywell TruStability SPI  
  * Download from [Github](https://github.com/huilab/HoneywellTruStabilitySPI)  
  * In Arduino IDE Select Sketch, then Include Library and click on add Zip Library then open the ZIP folder that you have just downloaded.

* RTClib.h  
  * Download from [Github](https://github.com/adafruit/RTClib)  
  * In Arduino IDE Select Sketch, then Include Library and click on add Zip Library then open the ZIP folder that you have just downloaded.

**Now you are done\!**   
Below are some additional instructions.  
---

**Connecting Your Arduino \- Compiling and Uploading**

* Plug in your Arduino to your laptop using a Micro-USB Cable to your computer. (If you do not have a USB port on your computer you will need a adapter)  

* Launch Arduino IDE and select the correct port with the dropdown menu  

* When you have the correct port selected and you are ready to Compile code to your Arduino. First compile the code to check for any errors beforehand.

* When there are no errors present in under output. You can now upload the code to your Arduino

---

**Running Blink example: testing connections (Computer with Arduino)**

Now that you have all the libraries downloaded, you can test the connection between the Sensor and your computer. 

* Head to File \> Examples \> Basics \> Blink to pull up the blink code that can be used to test if the sensor is connected to your computer (Will need a adaptor to connect)  and can have code uploaded to it  
  * Upload the code and look at the sensor when the code finish uploading to check it the light is blinking

  **Installing Arduino**

[image1]: <>

[image2]: <>

[image3]: <>

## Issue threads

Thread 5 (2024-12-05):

Freezing Error with New Code

M-Bellamy-0, 2024-12-05:
Version 4.5-Current begets an error. There are slight differences with these versions and 4_1

Closed 2025-01-24.

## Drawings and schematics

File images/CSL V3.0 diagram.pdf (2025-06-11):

# Community Sensor Lab: V3.0

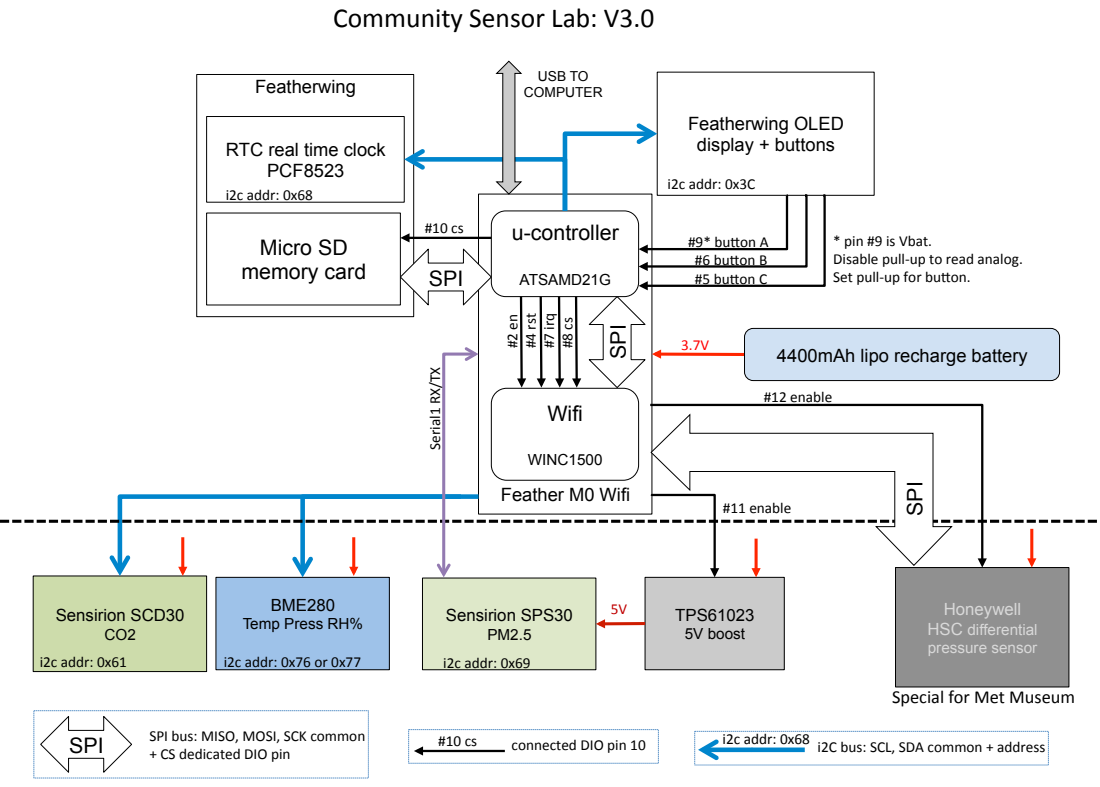
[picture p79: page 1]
Feather M0 Wifi; u-controller; ATSAMD21G; Wifi; WINC1500; SPI; #4 rst; #7 irq #8 cs; Featherwing; Micro SD; memory card; Featherwing OLED display + buttons; i2c addr: 0x3C; Sensirion SCD30 CO2; Sensirion SPS30 PM2.5; i2c addr: 0x61; i2c addr: 0x76 or 0x77; i2c addr: 0x69; Honeywell HSC differential pressure sensor; #11 enable; TPS61023 5V boost; #12 enable; 4400mAh lipo recharge battery; USB TO COMPUTER; Serial1 RX/TX; SPI bus: MISO, MOSI, SCK common; connected DIO pin 10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

RTC real time clock
PCF8523
i2c addr: 0x68

* pin #9 is Vbat.
Disable pull-up to read analog.
Set pull-up for bu<on.

Special for Met Museum SPI

BME280
Temp Press RH%

+ CS dedicated DIO pin

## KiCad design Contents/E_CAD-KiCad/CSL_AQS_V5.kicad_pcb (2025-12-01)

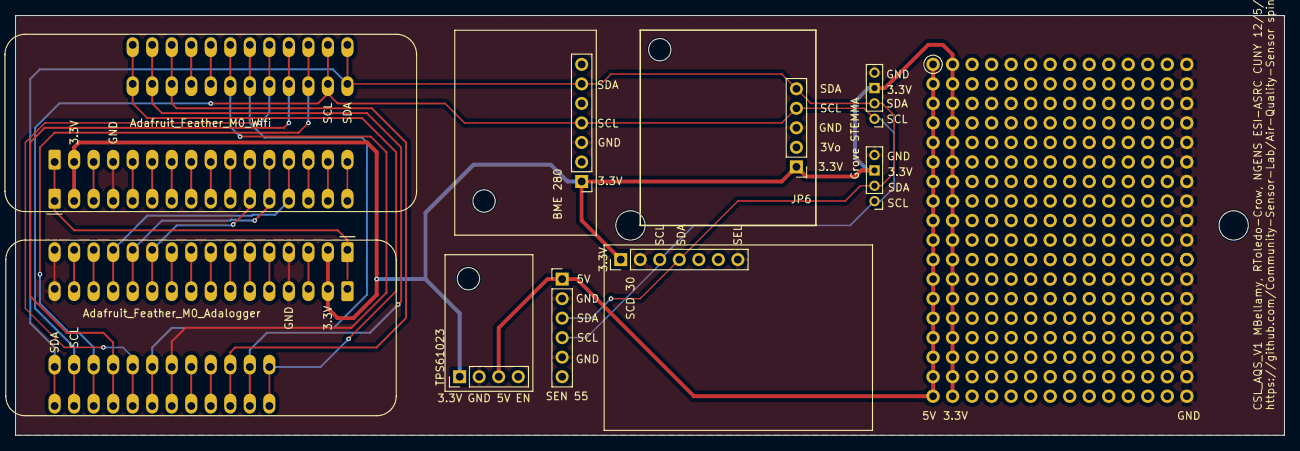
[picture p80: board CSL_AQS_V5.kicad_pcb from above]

Board: 2 copper layers, 165.1 x 54.6 mm, 9 parts (0 on the bottom side), 14 nets.

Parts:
A1: Adafruit_Feather_M0_Wifi
A2: Adafruit_Feather_M0_Adalogger; Adafruit_Feather
J2, J3: Grove STEMMA; PinHeader_1x04_P2.00mm_Vertical
JP2: TPS61023; PinHeader_1x04_P2.54mm_Vertical
JP6: SCD41; PinHeader_1x05_P2.54mm_Vertical
JP7: BME280; PinHeader_1x07_P2.54mm_Vertical
JP8: SEN 55; PinHeader_1x06_P2.54mm_Vertical
JP10: SCD 30; PinHeader_1x07_P2.54mm_Vertical

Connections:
3.3V: A1.2 (3V3), A2.2 (3V3), J2.3, J3.3, JP2.1, JP6.1, JP7.1, JP10.1
5V: JP2.3, JP8.1
ENA: A1.23 (D11), A2.23 (D11)
GND: A1.4 (GND), A2.4 (GND), A2.16 (GND), J2.4, J3.4, JP2.2, JP6.3, JP7.3, JP8.2, JP8.5, JP10.2, JP10.7
unnamed: A1.22 (D10), A2.22 (D10)
unnamed: A1.27 (EN), A2.27 (EN)
unnamed: A1.13 (MISO/D22), A2.13 (MISO/D22)
unnamed: A1.12 (MOSI/D23), A2.12 (MOSI/D23)
unnamed: A1.11 (SCK/D24), A2.11 (SCK/D24)
unnamed: A1.26 (USB), A2.26 (USB)
unnamed: A1.28 (VBAT), A2.28 (VBAT)
unnamed: A1.1 (~RESET), A2.1 (~RESET)
SCL: A1.18 (SCL/D21), A2.18 (SCL/D21), J2.1, J3.1, JP6.4, JP7.4, JP8.4, JP10.3
SDA: A1.17 (SDA/D20), A2.17 (SDA/D20), J2.2, J3.2, JP6.5, JP7.6, JP8.3, JP10.4

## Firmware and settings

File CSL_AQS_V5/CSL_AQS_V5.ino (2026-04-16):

/*!
   COMMUNITY SENSOR LAB - AIR QUALITY SENSOR

   featherM0-Wifi + featherwing adalogger-SD-RTC +  OLED display 

   The SCD30 has a minimum power consumption of 5mA and cannot be stop-started. It's set to 55s (30s nominal)
   sampling period and the featherM0 sleeps for 2 x 16 =32s, wakes and waits for data available.
   Button A toggles display on/off but must be held down for 16s max and then wait 16s to toggle again.

   Logs: 
   RTC - DateTime,
   SCD30 - Carbon Dioxide Concentration , Temperature , Relative Humidity, 
   SCD41 - Carbon Dioxide Concentration, Temperature , Relative Humidity, 
   BME 280 - Temperature , Pressure, Relative Humidity, 
   Microcontroller, Program  - Battery Voltage mV, stat
   Sen5X - Mass Concentration Pm1, Mass Concentration Pm2.5, Mass Concentration Pm4, Mass Concentration Pm10,
   Number Concentration Pm0.5, Number Concentration Pm1, Number Concentration Pm2.5, Number Concentration Pm4, Number Concentration Pm10,
   Typical Particle Size, Ambient Relative Humidity, Ambient Temperature, 
   VOC Index, NOx Index

   https://github.com/Community-Sensor-Lab/Air-Quality-Sensor

   Global status is in uint8_t stat in bit order:
   0-  0000 0000 0x00Starting state 
   1-  0000 0001 0x01 SD card not present
   2-  0000 0010 0x02 SD could not create file
   3-  0000 0011 0x03 RTC failed
   4-  0000 0100 0x04 SCD30 sensor not available
   5-  0000 0101 0x05 SCD30 sensor timeout
   6-  0000 0110 0x06 SCD41 sensor not available
   7-  0000 0111 0x07 SCD41 sensor timeout
   8-  0010 1000 0x08 BME280 sensor malfunction
   9-  0100 1001 0x09 BME280 sensor timeout
   10- 0000 1010 0x0A SEN5X sensor malfunction
   11- 0000 1011 0x0B SEN5X sensor timeout
   12- 0000 1100 0x0C SSL Connection: google.com ssl connection error
   13- 0000 1101 0x0D Provisioning error 
   14- 0000 1110 0x0E
   15- 0000 1111 0x0F
 
   RICARDO TOLEDO-CROW NGENS, ESI, ASRC, CUNY,
   AMALIA TORRES, CUNY, July 2021

*/
#include <SPI.h>
#include <SD.h>
#include <Wire.h>
#include <Adafruit_SleepyDog.h>
#include "RTClib.h"
// #include "SparkFun_SCD30_Arduino_Library.h"
#include "SparkFun_SCD4x_Arduino_Library.h"
#include <Adafruit_GFX.h>
#include <Adafruit_SH110X.h>
#include <Adafruit_Sensor.h>
#include <Adafruit_BME280.h>
#include <SensirionI2CSen5x.h>
#include <WiFi101.h>
#include <FlashStorage.h>


#define VBATPIN A7  // this is also D9 button A disable pullup to read analog
#define BUTTON_A 9  // Oled button also A7 enable pullup to read button
#define BUTTON_B 6  // oled button
#define BUTTON_C 5  // oled button
#define SD_CS 10    // Chip select for SD card default for Adalogger
#define MAXBUF_REQUIREMENT 48

#if (defined(I2C_BUFFER_LENGTH) && (I2C_BUFFER_LENGTH >= MAXBUF_REQUIREMENT)) || (defined(BUFFER_LENGTH) && BUFFER_LENGTH >= MAXBUF_REQUIREMENT)
#define USE_PRODUCT_INFO
#endif


// Function prototypes
void initializeOLED();
bool toggleButton(uint8_t button, bool state, bool &buttonState, int &prevTime, int debounce);

void initializeSCD30();
String readSCD30();

void initializeSCD41();
String readSCD41();

void initializeBME280();
String readBME280();

void initializeSen5x();
String readSen5x();

File initializeSD();

void resetI2C() {
  Wire.end();
  delay(100);
  Wire.begin();
  delay(100);
}

void payloadUpload(String payload);
void printMacAddress(byte mac[]);
void AP_getInfo(String &ssid, String &passcode, String &gsid);
void makeMACssidAP(String startString);

void payloadUpload(String payload);
void initializeClient();

// Force Provisioning
bool force_pro = false;

//Interrupt Handler
void A() {
  force_pro = true;
}

// Global Variables

char outstr[160];
int32_t Tsleep = 0;
bool displayState = true;
bool buttonAstate = true;
int lastTimeToggle = 0;
int timeDebounce = 100;

char server[] = "script.google.com";

String payload = "{\"command\":\"appendRow\",\"sheet_name\":\"Sheet1\",\"values\":";

// char header[] = "DateTime, CO2_scd30, T_scd30, RH_scd30, T_bme280, P_bme280, RH_bme280, dvbat(mV), status, \
 mC_Pm1_sen5x, mC_Pm2_sen5x, mC_Pm4_sen5x, mC_Pm10_sen5x, nC_Pm0_5_sen5x, nC_Pm1_sen5x, nC_Pm2_sen5x, nC_Pm4_sen5x, nC_Pm10_sen5x, typPartSize_sen5x, \
 ambientRH_sen5x, ambientTemp_sen5x, vocIndex_sen5x, noxIndex_sen5x";
char header[] = "DateTime, CO2_scd41, T_scd41, RH_scd41, T_bme280, P_bme280, RH_bme280, dvbat(mV), status, \
 mC_Pm1_sen5x, mC_Pm2_sen5x, mC_Pm4_sen5x, mC_Pm10_sen5x, nC_Pm0_5_sen5x, nC_Pm1_sen5x, nC_Pm2_sen5x, nC_Pm4_sen5x, nC_Pm10_sen5x, typPartSize_sen5x, \
 ambientRH_sen5x, ambientTemp_sen5x, vocIndex_sen5x, noxIndex_sen5x";

int status = WL_IDLE_STATUS;
String ssidg, passcodeg, gsidg;
uint8_t stat = 0;

// SCD30 & SCD40
//uint16_t CO2scd30;
uint16_t CO2scd41;


// BME
float Tbme = 0;
float Pbme = 0;
float RHbme = 0;

//SEN 55
uint16_t error;
float massConcentrationPm2p5 = 0;
float vocIndex = 0;
float noxIndex = 0;


// Sensor Componentns
Adafruit_SH1107 display = Adafruit_SH1107(64, 128, &Wire);
Adafruit_BME280 bme280;
SensirionI2CSen5x sen5x;
RTC_PCF8523 rtc;
WiFiSSLClient client;
File logfile;

// SCD30 scd30;
SCD4x scd41(SCD4x_SENSOR_SCD41);


void setup() {
  pinMode(VBATPIN, INPUT);
  pinMode(LED_BUILTIN, OUTPUT);
  digitalWrite(LED_BUILTIN, LOW);

  Serial.begin(9600);
  delay(5000);
  Serial.println(__FILE__);
  WiFi.setPins(8, 7, 4, 2);

  initializeOLED();
  initializeSCD41();
  // initializeSCD30(25);
  initializeBME280();
  initializeSen5x();

  initializeRTC();
  logfile = initializeSD();

  delay(3000);

  //Set Interrupt
  pinMode(BUTTON_A, INPUT_PULLUP);
  attachInterrupt(digitalPinToInterrupt(BUTTON_A), A, CHANGE);


  if (!check_valid()) {
    AP_getInfo(ssidg, passcodeg, gsidg);
  } else {
    display.clearDisplay();
    display.setCursor(0, 0);
    display.println("Connecting to previously saved network");
    display.display();
    storeinfo(ssidg, passcodeg, gsidg);
  }
  // TURN SEN55 TO IDLE
  sen5x.stopMeasurement();
  Serial.print("Stop measurement executed");
  Serial.print("\n");
}


void loop(void) {

  uint8_t ctr = 0;

  Wire.begin();
  delay(10);

  // MEASUREMENTS
  // String scd30String = readSCD30(100);
  String scd41String = readSCD41();
  String bmeString = readBME280();
  DateTime now;
  now = rtc.now();

  // START SEN55 IN NO PM MODE FOR 30S WARMUP
  error = sen5x.startMeasurementWithoutPm();
  Serial.print("Measurement (No PM) start");
  Serial.print("\n");
  delay(30000);

  // START SEN55 IN FULL MODE FOR 30S MORE WARMUP
  error = sen5x.startMeasurement();
  Serial.print("Complete Measurement start");
  Serial.print("\n");
  delay(30000);

  // MEASUREMENTS
  String sen5xString = readSen5x();

  // TURN SEN55 TO IDLE
  sen5x.stopMeasurement();
  Serial.print("Stop measurement executed");
  Serial.print("\n");
  delay(1000);

  pinMode(VBATPIN, INPUT);  // read battery voltage
  float measuredvbat = analogRead(VBATPIN) * 0.006445;
  pinMode(BUTTON_A, INPUT_PULLUP);
  delay(5000);

  sprintf(outstr, "%02u/%02u/%02u %02u:%02u:%02u, ", now.year(), now.month(), now.day(), now.hour(), now.minute(), now.second());

  // payloadUpload( payload + String("\"") + String(outstr) + scd30String + bmeString + String(measuredvbat) + String(", ") + String(stat) + String(", ") +sen5xString);
  payloadUpload(payload + String("\"") + String(outstr) + scd41String + bmeString + String(measuredvbat) + String(", ") + String(stat) + String(", ") + sen5xString);

  Serial.println(header);
  // Serial.println(String(outstr) + scd30String + bmeString + String(measuredvbat) + String(", ") + String(stat) + String(", ") + sen5xString);
  Serial.println(String(outstr) + scd41String + bmeString + String(measuredvbat) + String(", ") + String(stat) + String(", ") + sen5xString);

  // logfile.println(String(outstr) + scd30String + scd41String + bmeString + String(measuredvbat) + String(", ") + String(stat) + String(", ") + sen5xString);
  logfile.println(String(outstr) + scd41String + bmeString + String(measuredvbat) + String(", ") + String(stat) + String(", ") + sen5xString);
  logfile.flush();  // Write to disk. Uses 2048 bytes of I/O to SD card, power and takes time

  Wire.end();
  delay(10);

  // SLEEP FOR 60S (FOR A 2MIN CYCLE)
  // sleep cycle
  for (int i = 1; i <= 8; i++) {  // 124s = 8x16s sleep, only toggle display
    displayState = toggleButton(BUTTON_A, displayState, buttonAstate, lastTimeToggle, timeDebounce);
    if (displayState) {  // On

      display.clearDisplay();
      display.setCursor(0, 0);
      display.printf("T: %.2f C\nP: %.2f mBar\nRH: %.2f%%\n", Tbme, Pbme, RHbme);
      display.printf("CO2: %d ppm\nPM2.5: %.2f ug/m^3\nVOCs: %.2f\nNOX: %.2f", CO2scd41, massConcentrationPm2p5, vocIndex, noxIndex);
      display.printf("\nBat: %.2f V", measuredvbat);
      display.display();
    } else {
      display.clearDisplay();
      display.display();
    };

    //int sleepMS = Watchdog.sleep();// remove comment for low power
    delay(8000);  // uncomment to debug because serial communication doesn't come back after sleeping
  }
}

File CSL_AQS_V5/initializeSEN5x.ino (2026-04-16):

/*!
* @brief
* @param
*/

void initializeSen5x() {
  Serial.println("starting Sen5x... ");
  Serial.begin(115200);
  Wire.begin();
  sen5x.begin(Wire);

  uint16_t error;
  char errorMessage[256];
  error = sen5x.deviceReset();
  if (error) {
    Serial.print("Error trying to execute deviceReset(): ");
    errorToString(error, errorMessage, 256);
    Serial.println(errorMessage);
  }

  float tempOffset = 0.0;

  error = sen5x.setTemperatureOffsetSimple(tempOffset);
  if (error) {
    Serial.print("Error trying to execute setTemperatureOffsetSimple(): ");
    errorToString(error, errorMessage, 256);
    Serial.println(errorMessage);
  } else {
    Serial.print("Temperature Offset set to ");
    Serial.print(tempOffset);
    Serial.println(" deg. Celsius (SEN54/SEN55 only");
  }

  error = sen5x.stopMeasurement();
  if (error) {
    Serial.print("Error trying to execute startMeasurement(): ");
    errorToString(error, errorMessage, 256);
    Serial.println(errorMessage);
  }

  Serial.println(F("SEN5X Connected"));
  display.println("SEN5X Connected");
  display.display();
}


/*!
* @brief
* @param
*/

String readSen5x() {
  float massConcentrationPm1p0 = 0;
  float massConcentrationPm4p0 = 0;
  float massConcentrationPm10p0 = 0;
  float numberConcentrationPm0p5 = 0;
  float numberConcentrationPm1p0 = 0;
  float numberConcentrationPm2p5 = 0;
  float numberConcentrationPm4p0 = 0;
  float numberConcentrationPm10p0 = 0;
  float typicalParticleSize = 0;
  float ambientHumidity = 0;
  float ambientTemperature = 0;

  uint16_t error;
  char errorMessage[256];

  delay(1000);

  // TODO: MAKE A PULL REQUEST TO EDIT READMEASSUMENT OPTIONS
  error = sen5x.readMeasuredValues(
    massConcentrationPm1p0, massConcentrationPm2p5, massConcentrationPm4p0,
    massConcentrationPm10p0, ambientHumidity, ambientTemperature, vocIndex,
    noxIndex);

  if (error) {
    Serial.print("Error trying to execute readMeasuredValues(): ");
    errorToString(error, errorMessage, 256);
    Serial.println(errorMessage);
  }

  error = sen5x.readMeasuredPmValues(
    massConcentrationPm1p0, massConcentrationPm2p5, massConcentrationPm4p0,
    massConcentrationPm10p0, numberConcentrationPm0p5, numberConcentrationPm1p0,
    numberConcentrationPm2p5, numberConcentrationPm4p0, numberConcentrationPm10p0,
    typicalParticleSize);

  // massConcentrationPm1p0, massConcentrationPm2p5,
  // massConcentrationPm4p0,massConcentrationPm10p0,
  // numberConcentrationPm0p5, numberConcentrationPm1p0,
  // numberConcentrationPm2p5, numberConcentrationPm4p0
  // numberConcentrationPm10p0, typicalParticleSize,
  // ambientHumidity, ambientTemperature, vocIndex, noxIndex,

  String sen5xString = String(massConcentrationPm1p0) + String(", ") + String(massConcentrationPm2p5) + String(", ") + String(massConcentrationPm4p0) + String(", ") + String(massConcentrationPm10p0) + String(", ") + String(numberConcentrationPm0p5) + String(",") + String(numberConcentrationPm1p0) + String(",") + String(numberConcentrationPm2p5) + String(",") + String(numberConcentrationPm4p0) + String(",") + String(numberConcentrationPm10p0) + String(",") + String(typicalParticleSize) + String(",") + String(ambientHumidity) + String(", ") + String(ambientTemperature) + String(", ") + String(vocIndex) + String(", ") + String(noxIndex);
  return sen5xString;
}

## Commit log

2025-06-10 Converted from Google Sheets to Markdown
    Switched from Google Sheets to Markdown for structured data storage
    Updated file paths to relative references for portability and simplicity
2025-06-11 Update 2. Installing-Arduino-and-Getting-Started.md
2025-06-12 Update 2. Installing-Arduino-and-Getting-Started-2.3.6.md
2025-06-12 Update 3. Soldering-Pins-and-Headers-on-Boards.md
2025-06-12 Update 4 Breadboard-Assembly-and-Component-Code-Testing.md
2025-06-13 Remove Documents/Air-Quality-Sensor folder
2025-06-13 Refactored soldering guide and restructured layout
2025-06-13 Restructure Arduino installation guide
2025-06-13 Add hover links and improve image placement in soldering guide
    - Added links to component datasheets and supplier pages
    - Included brief descriptions for key sensors (BME280, SCD41)
    - Added tool reference links for community builders
    - Moved component layout image to logical position after materials list
    - Added image caption for better context
2025-06-14 Restructure Feather M0 WiFi setup guide - Add logical section hierarchy and clear headings - Group related steps for better flow - Add hover links to components and resources - Include troubleshootin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
2025-06-14 docs: reorganize sensor assembly guide with improved structure and flow
    - Add logical section hierarchy and clear progression
    - Group materials by category with helpful reference links
    - Move preliminary setup steps before sensor assembly
    - Standardize testing procedures across all sensors
    - Add safety warnings and best practices section
    - Improve visual formatting while preserving all original content
2025-06-14 Restructure sensor code activity README for improved flow and accessibility
2025-06-14 Enhance sensor building guide with clear headings and helpful links
2025-06-14 Improve README: reorganize AQS assembly steps, fix typos, add supplier links
2025-06-16 added 9.8 Assembley of AQS Monitor on PCB Board
2025-07-07 Update CSL_AQS_V5.ino
    commented out scd30 library and fixed force_pro reference
    [CSL_AQS_V5.ino]
2025-07-07 re added delay after pinMode to stabilize the button (A).
    [CSL_AQS_V5.ino]
2025-08-25 Added provision flowchart image
2025-08-25 Add ESP32 provisioning flowchart image
2025-08-25 Remove outdated flowchart and add ESP32 provisioning reference
2025-08-25 Add ESP32 provisioning flowchart reference after Step 10
2025-08-25 Credit Fahmin for ESP32 provisioning flowchart in README
2025-08-27 Update README-DETAILED 3.5 with Fahmin's flowchart credit
2025-09-08 Update Readme.md
    professional to printed
2025-12-01 Added E_CAD files for PCB
    [Adafruit-Adalogger-FeatherWing.kicad_sch, Adafruit-OLED-FeatherWing.kicad_sch, Adafruit-TPS61023.kicad_sch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]
2025-12-05 Add M_CAD Folder
    Moved over M_CAD folder from branch to main
    Added antenna mount in M_CAD folder
    [3in End Cap.0002.ipt, 3in End Cap.SLDPRT, 3in End Cap.ipt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]
2025-12-05 Antenna
    Added the READme and corresponding images for the new antenna addition to the AQS system
    [LBracket1.step, SEN5X Mount V4 Antena.ipt]
2025-12-05 Moved Antenna Readme Location
2025-12-05 Reverted Antenna Location
2025-12-05 Created Antenna Folder w/ Images
2026-02-13 CSL_AQS_V5_timing
    Optimization of SEN55x:
    -Incorporated idle, partial, and full measurement modes
    -Shifted some code to minimize current consumption
2026-04-16 Clear Bus
    Testing a wire end begin fix to clear the system I2C bus on every loop
    [initializeSEN5x.ino]

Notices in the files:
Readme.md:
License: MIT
